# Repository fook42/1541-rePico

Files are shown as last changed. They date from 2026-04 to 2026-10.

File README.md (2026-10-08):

# 1541-rePico
replacement of analog-part of Commodore 1541-Floppy devices based on Pi-Pico(2)

## preface/credits ##
this project was derived from the original 1541-rebuild from Thorsten Kattanek (https://github.com/ThKattanek/1541-rebuild) !
parts of his code were taken from there and adopted for Raspberry Pico and modified to handle disk images differently. Thanks!

the C64/C16 selector-programm was developed and implemented by [PeiselUlli](https://github.com/peiselulli69) !

thanks to [BensonRSI](https://github.com/BensonRSI) for adding debugging documentation, dev-containers and github-magic !

## Features ##

latest version:
- software: 1.7.1
- hardware: 1.7.0

### Hardware ###

single board, size 59mm x 60 mm

- Raspberry Pico2 socket/solder-pads
- VIA 40pin socket
- levelshifter (BSS138 & 74LVC4245) for stable signals
- connectors for
  - I2C Display
  - SPI SD-Card adapter
  - Rotary-Encoder + Switch (KY-040 compatible)
  - Write-Protect-Signal

one size fits for all 1541 models.

## how to build ##

-> [interactive BOM](/hardware/bom/ibom.html)

### Software ###

#### Pico2 Firmware ####

- mounting of D64 & G64 & PRG Files
- 35 & 42 track image files supported
- read and write access for both D64 & G64
- sd-card hotswap feature (refresh of directory content)

#### C64/C16/VIC20 Image Selector ####

- browsing through sd-card content via "virtual disk-image"
  - subdirectory support
  - 4 way scrolling
- highlighting and selecting of different file-types (D64,G64,PRG,Folder)
- simple mounting and also fastloading of selected entry
- supports C64-PAL, C64-NTSC and C16 computers

## how to build ##

### prepare tools (linux) ###

```
sudo apt install cmake ninja-build libusb-1.0-0-dev build-essential pkg-config python3 xxd gcc-arm-none-eabi libnewlib-arm-none-eabi libstdc++-arm-none-eabi-newlib acme
```

### pico-sdk ###

from : <https://github.com/raspberrypi/pico-sdk>

- clone this repo
- create a environment variable called "PICO_SDK_PATH" which points to this repo
- place a "export PICO_SDK_PATH= <path to your pico-sdk>" at the end of your .profile script
- then cd into this repo-folder and initialize the mbedtls submodule (picotool mentiones this)

all in one:
```
git clone https://github.com/raspberrypi/pico-sdk.git
export PICO_SDK_PATH=$(pwd)/pico-sdk
echo "export PICO_SDK_PATH=$PICO_SDK_PATH" >> ~/.profile"
cd pico-sdk
git submodule update --init lib/mbedtls
```

### picotool ###

from : <https://github.com/raspberrypi/picotool>

- clone this repo
- install the picotool as described in README.md and BUILDING.md file there

```
git clone https://github.com/raspberrypi/picotool.git
```

### build steps ###

make sure submodules are initialized and up-to-date (like NoOS-Fat-lib)

```
git submodule update --init
git pull --recurse-submodules
```

prepare build-folder / configure Ninja for build the cmake project

```
cd firmware
mkdir build
cd build
cmake -G Ninja .. -D BUILD_MENUPRG=OFF -D COMPRESS_MENUPRG=ON -D PCB_VERSION=17
```

optional cmake variables are:

| Variable | Values | Description |
| :--- | :---: | :--- |
| BUILD_MENUPRG | ON*/OFF | let ACME compile the provided menu.asm-code. Otherwise the shipped, precompiled "menu.prg" will be used. |
| COMPRESS_MENUPRG | ON*/OFF | uses dali binary compression to generate a smaller menu-prg object |
| PCB_VERSION | 0..17* | defines which PCB version is used -> enables specific code features according to pcb-layout (like sound output) |

(* is default)

now trigger a build

```
ninja
```

## howto flash ##

connect your pico2 via USB cable and use picotool to flash the firmware

```
picotool load -t uf2 1541-rePico.uf2 -x -f
```

## debugging with OpenOCD ##

### prerequisites ###

- **CMSIS-DAP Compatible Debugger** (e.g., Raspberry Pi Debug Probe, STLink, or SEGGER J-Link) 
get binaries for a pico here : https://github.com/raspberrypi/debugprobe
- **OpenOCD** installed ( built in devcontainer or  with "build_openocd.sh")
- **gdb-multiarch** for GDB debugging ( preinstalled in devcontainer )

### setup ###

1. Connect your debugger to the Pico using the SWD pins:
   - SWCLK → GPIO 24 (or pin 20)
   - SWDIO → GPIO 25 (or pin 21)
   - GND → GND

2. Ensure the debugger is connected via USB to your development machine

### starting OpenOCD ###

Start OpenOCD in a terminal:

```
openocd -f interface/cmsis-dap.cfg -f target/rp2350.cfg
```

OpenOCD will listen on port 3333 for GDB connections.

### debugging in VS Code ###

VS Code launch configurations are available:

**Pico Debug (Cortex-Debug)** - Integrated debugging with OpenOCD

#### using Cortex-Debug (recommended) ####

Press `F5` or select "Pico Debug (Cortex-Debug)" from the Run menu. This will:
- Start OpenOCD automatically
- Load your firmware
- Break at `main()`
- Allow step debugging, breakpoints, and variable inspection

#### using external OpenOCD ####

1. Start OpenOCD in a terminal (see above)
2. Select "Pico Debug (Cortex-Debug with external OpenOCD)" from Run menu
3. VS Code will connect to the running OpenOCD instance

### useful GDB commands ###

When debugging, common GDB commands include:

```
continue         # Resume execution
step             # Step into function
next             # Step over function
break <func>     # Set breakpoint at function
break <file>:<line>  # Set breakpoint at file:line
print <var>      # Print variable value
display <var>    # Show variable on each step
backtrace        # Show call stack
```

### troubleshooting ###

**"Device not found"**: 
- Check CMSIS-DAP debugger is connected
- Verify SWD pin connections
- Try `openocd -d` for debug output
- Connect the USB for the targetdevice, then the USB for debugprobe
( to keep correct order of /dev/ttyACMx )

**GDB connection failed**: 
- Ensure OpenOCD is running on port 3333
- Check firewall settings

# documentation #

## project documentation ##

t.b.d.

## supported disk formats ##

currently [D64](/doc/D64.TXT) and [G64](/doc/G64.TXT) are supported as for reading and writing.  
as bonus, **PRG** files can be loaded by an on-the-fly routine that creates a valid D64 image out of it.

additionaly a small tool [conv_x64](/tools) is provided that allows easy conversion from one to the other on you linux-pc.

## Pictures ##

impressions of current setup and PCB can be found [here](/doc/pictures).

## Links ##

- great collection of basics about disk-image-formats can be found here:  
<https://ist.uwaterloo.ca/~schepers/formats.html>

- forum64 project discussion thread (base of 1541-rebuild and 1541-rePico)  
<https://www.forum64.de/index.php?thread/59884-laufwerk-der-1541-emulieren>

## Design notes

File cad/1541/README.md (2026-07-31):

# 1541-Front Bezel

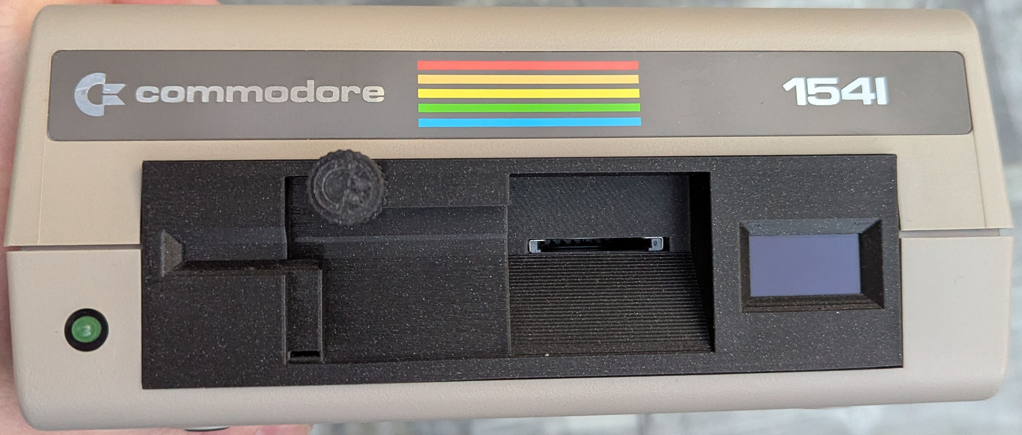
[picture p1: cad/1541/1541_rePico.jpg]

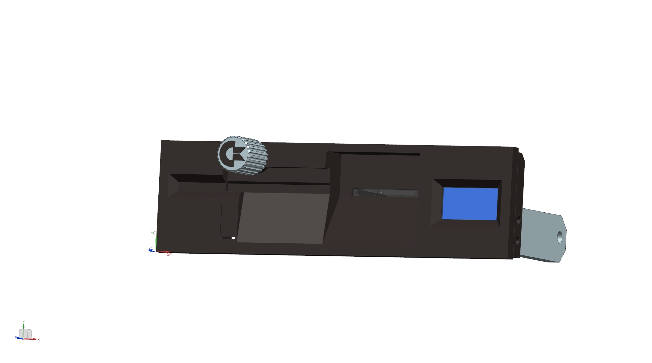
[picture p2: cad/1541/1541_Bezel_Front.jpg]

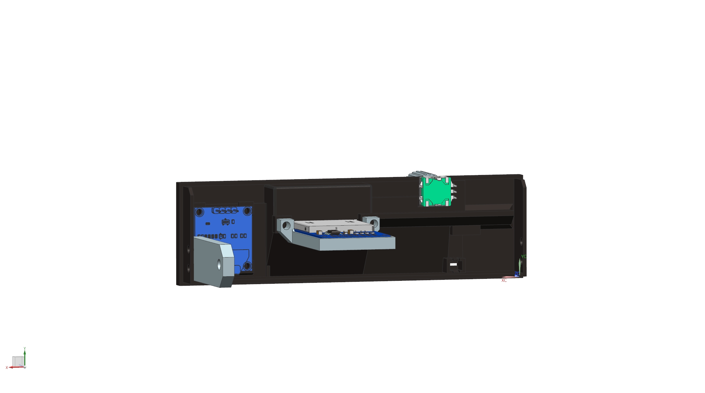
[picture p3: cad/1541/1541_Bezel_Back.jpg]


## CAD Files for printing

| Amount | Part |
| :--- | :---: |
| 1 | 1541_Bezel.stp | 
| 1 | SD_Tray.stp |
| 1 | Knob.stp |
| 2 | 2xSide_Holder_LR.stp |

### Print Settings

|Orientation (Bezel)| 45 deg |
| :--- | :---: |
|Layer Height | 0.15 |
|Wall loops | 5 |
|Top shell Layers |5|
|Bottom shell Layers |5|
|Infill density |20%|
|Infill pattern |Grid|

### Print Direction

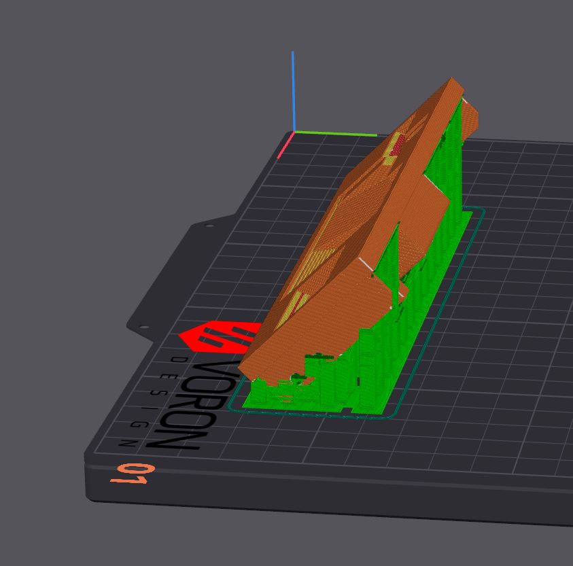
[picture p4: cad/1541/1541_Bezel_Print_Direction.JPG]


## BOM

| Front Bezel | |
| :--- | :---: |
| Amount | Part |
| 2 | Heat Set Insert Nut M3 x D5.0 mm x L4.0 mm |

| Display | |
| :--- | :---: |
| Amount | Part |
| 4 | Selftapping M2.6 x 6mm | 

| SD-Card Tray | |
| :--- | :---: |
| Amount | Part |
| 2 | Selftapping M2 x 5 mm | 
| 2 | BHCS M3 x 8 mm | 

| Side Holder | |
| :--- | :---: |
| Amount | Part |
| 6 | BHCS M3 x 6 mm | 
| 2 | M3 Washer | 
| 6 | Heat Set Insert Nut M3 x D5.0 mm x L4.0 mm |

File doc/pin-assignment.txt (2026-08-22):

### 1541-rePico Mapping ###
## (stand: 2026-08-06)

pico2 PIN-mapping:
# 17 für die VIA6522 Verbindung (PA0-PA7, BRDY, SYNC, SOE, SOE_GA, WP, MTR, STP0, STP1, OE)
SOE  = GP0
OE   = GP1
SYNC = GP2
SOE_GA = GP3
MTR  = GP4
WPS  = GP5
STP0 = GP6
STP1 = GP7
PA0  = GP8
PA1  = GP9
PA2  = GP10
PA3  = GP11
PA4  = GP12
PA5  = GP13
PA6  = GP14
PA7  = GP15
BRDY = GP22

# 4 für die SD-Karte (SPI)
MISO = GP16
CS   = n.c. (nicht belegt)
SCK  = GP18
MOSI = GP19

# 2 fürs Display (nur per I2C angeschlossen)
SDA  = GP20
SCL  = GP21

# 3 für den Drück-Dreh-Schalter
BT1  = GP27
BT2  = GP26
BT3  = GP28

# Anschluss Sound-Buzzer
SOUND = GP17

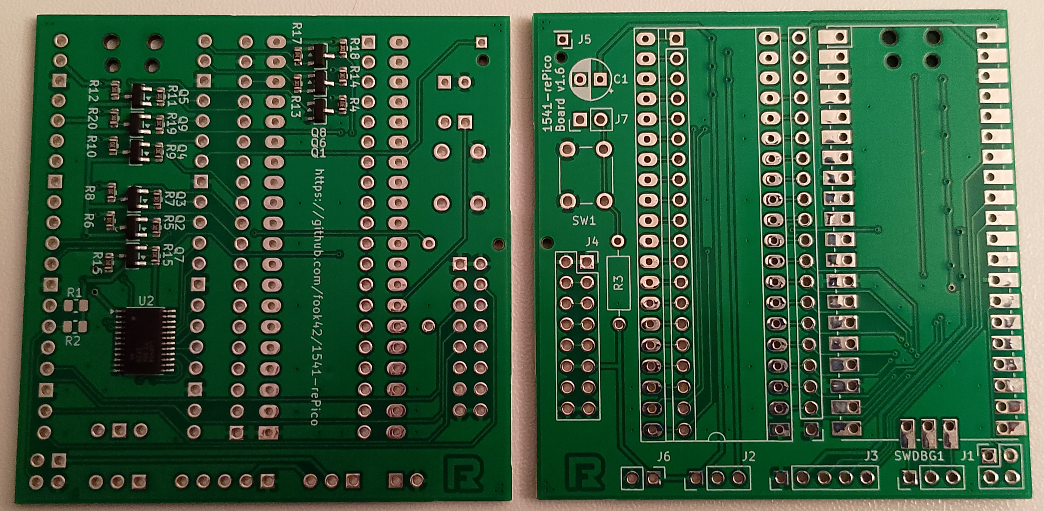
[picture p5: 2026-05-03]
doc/pictures/PCB_version16.jpg

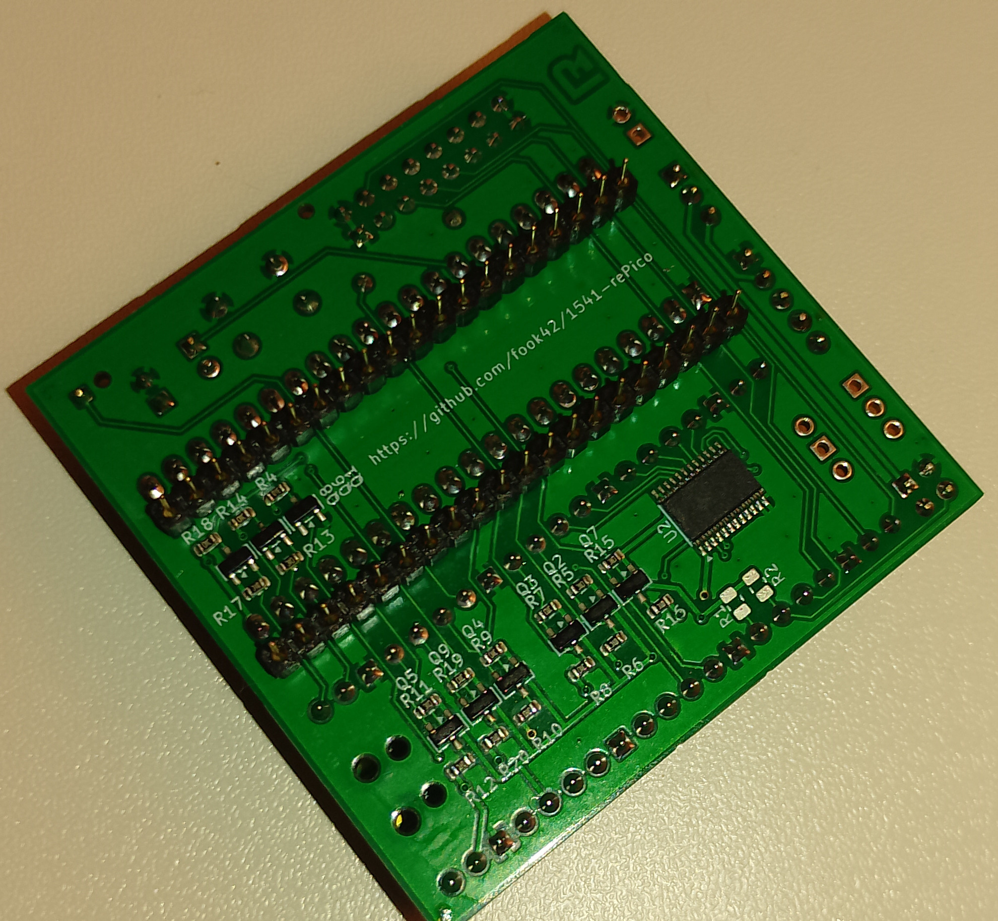
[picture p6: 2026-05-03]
doc/pictures/RePico_v16_bottom.jpg

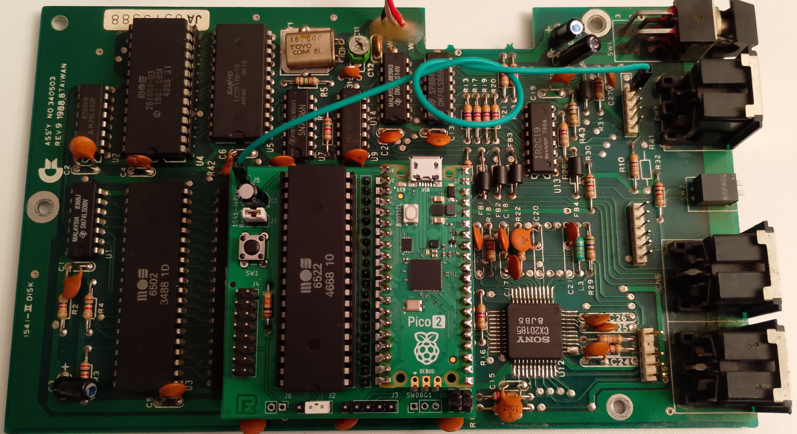
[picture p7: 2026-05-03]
doc/pictures/1541-II_with_rePico.jpg

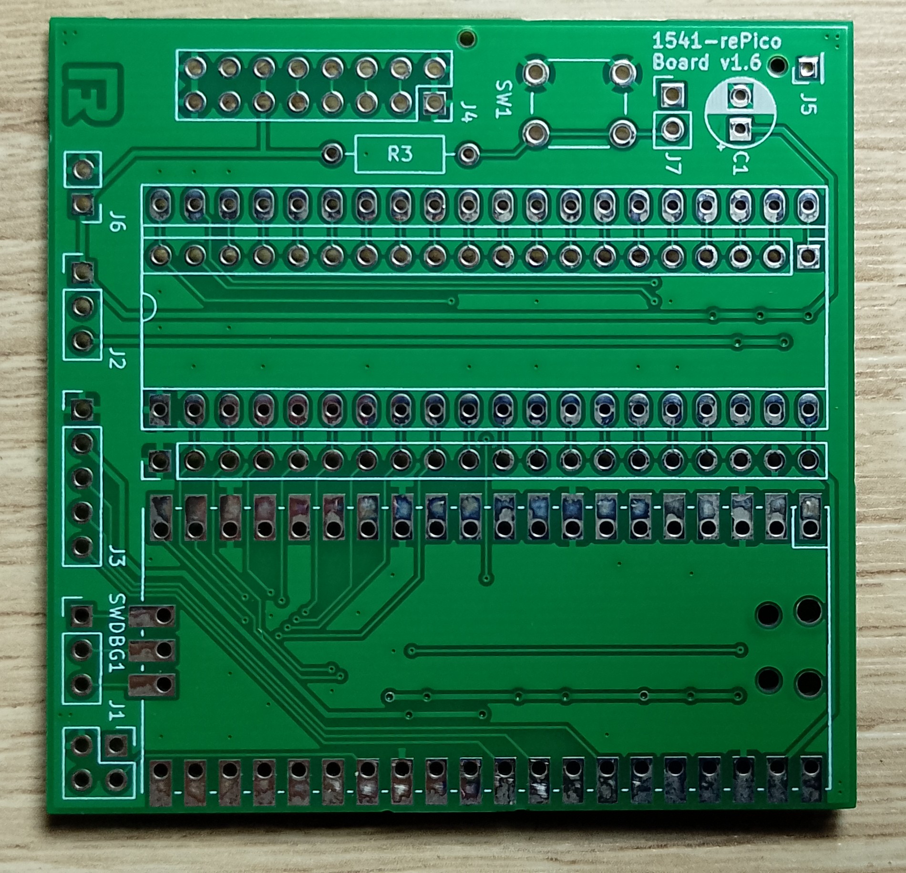
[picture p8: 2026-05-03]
doc/pictures/PCB_V16_top.jpg

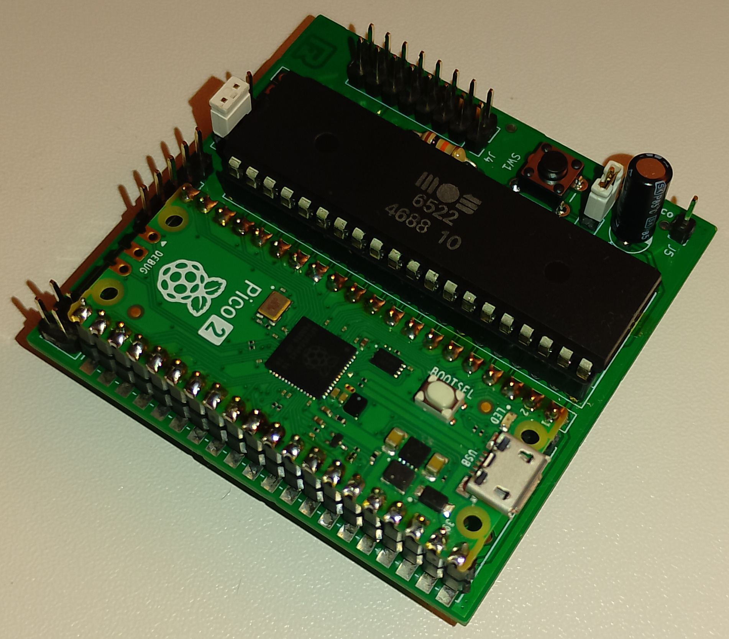
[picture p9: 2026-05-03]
doc/pictures/RePico_v16_top.jpg

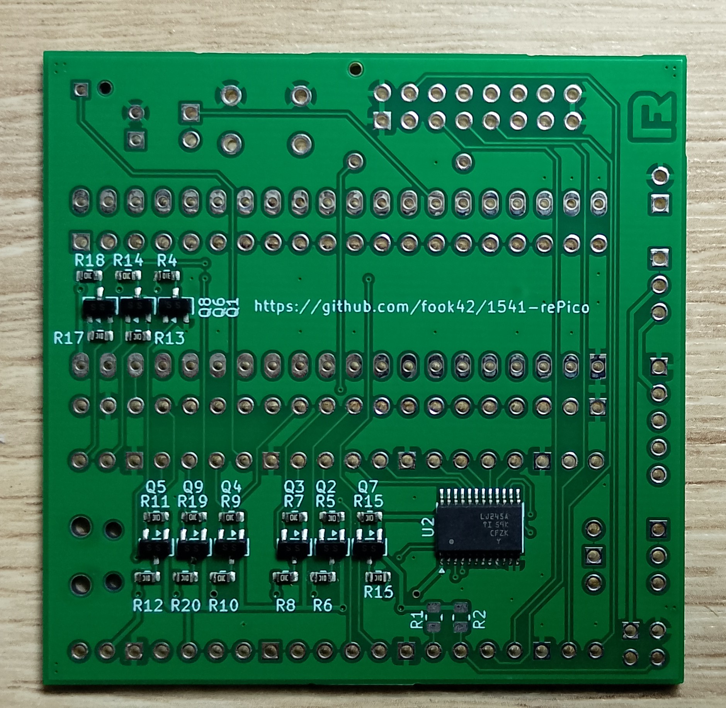
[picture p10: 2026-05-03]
doc/pictures/PCB_V16_bottom.jpg

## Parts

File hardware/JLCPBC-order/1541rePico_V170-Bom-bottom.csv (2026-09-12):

Comment | Designator | Footprint | JLCPCB Part #
1M | R4 | Resistor_SMD:R_0603_1608Metric | C22935
SN74LVC4245A | U2 | Package_SO:TSSOP-24_4.4x7.8mm_P0.65mm | C7859
BSS138 | Q1,Q2,Q3,Q4,Q5,Q6,Q7,Q8,Q9 | Package_TO_SOT_SMD:SOT-23 | C7420339
10k | R5,R6,R7,R8,R9,R10,R11,R12,R13,R14,R15,R16,R17,R18,R19,R20 | Resistor_SMD:R_0603_1608Metric | C25804

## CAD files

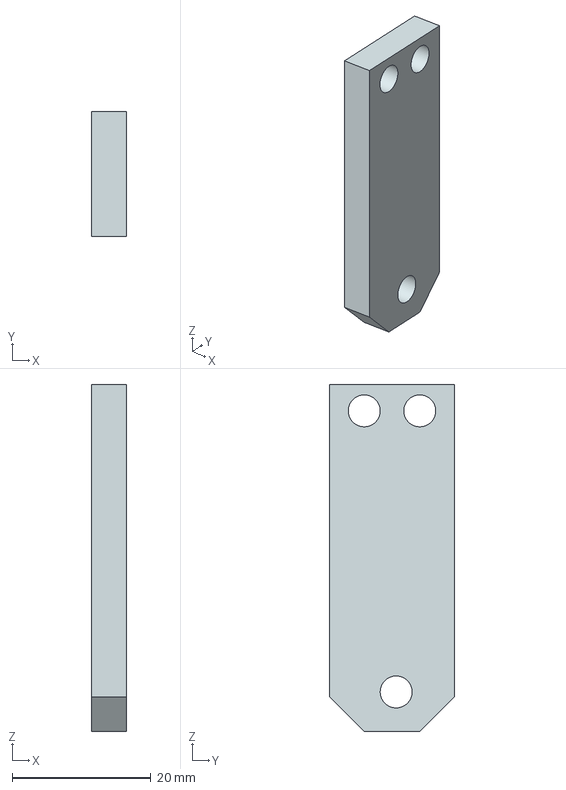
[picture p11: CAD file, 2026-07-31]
cad/1541/2xSide_Holder_LR.stp
5.00 x 18.0 x 50.0 mm

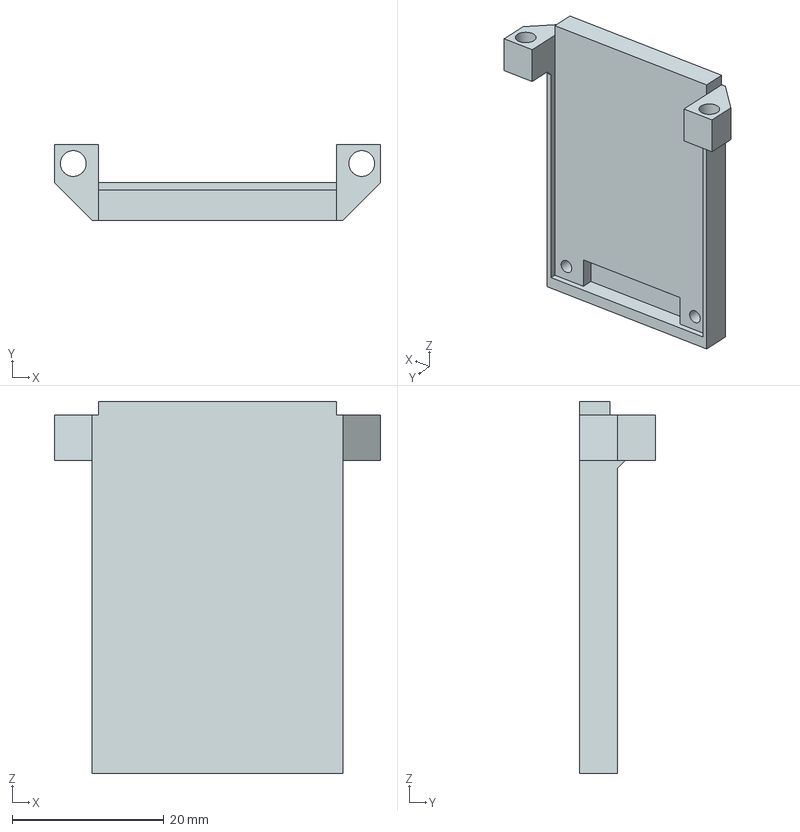
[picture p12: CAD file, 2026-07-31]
cad/1541/SD_Card_Tray.stp
43.0 x 10.0 x 49.0 mm

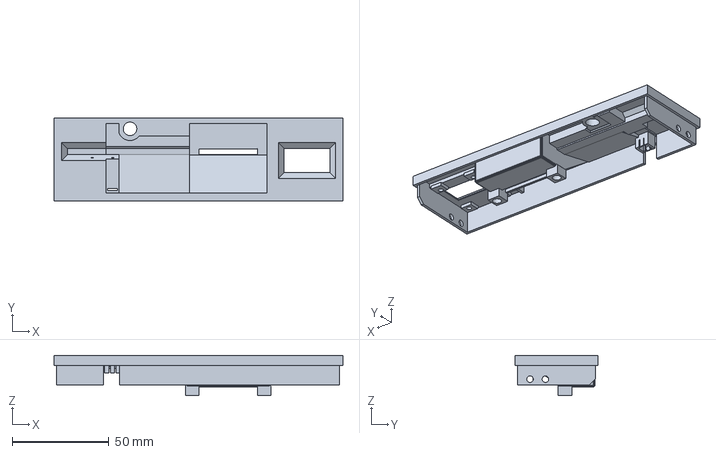
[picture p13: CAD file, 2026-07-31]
cad/1541/1541_Bezel.stp
149.2 x 43.0 x 20.8 mm

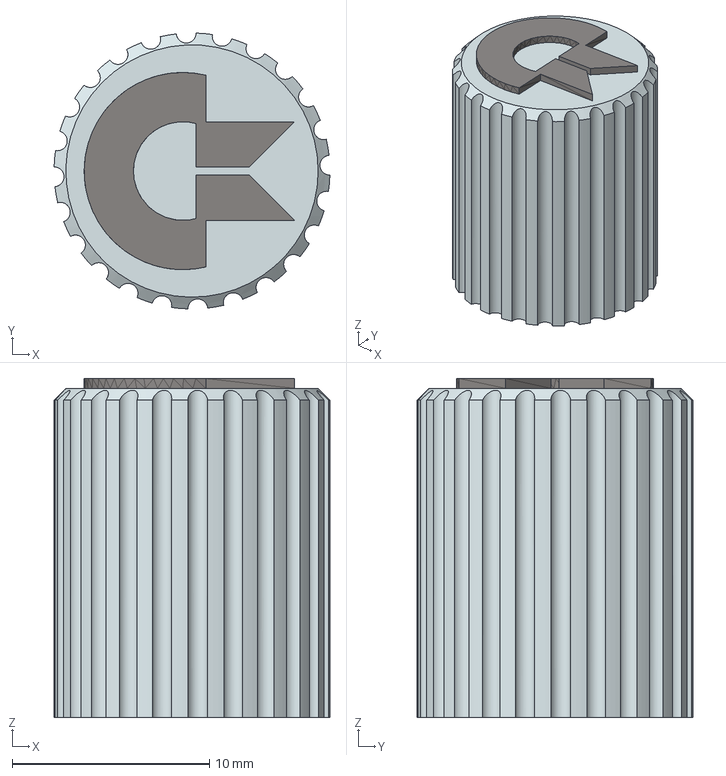
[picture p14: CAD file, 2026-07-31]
cad/1541/Knob.stp
14.0 x 14.0 x 17.2 mm

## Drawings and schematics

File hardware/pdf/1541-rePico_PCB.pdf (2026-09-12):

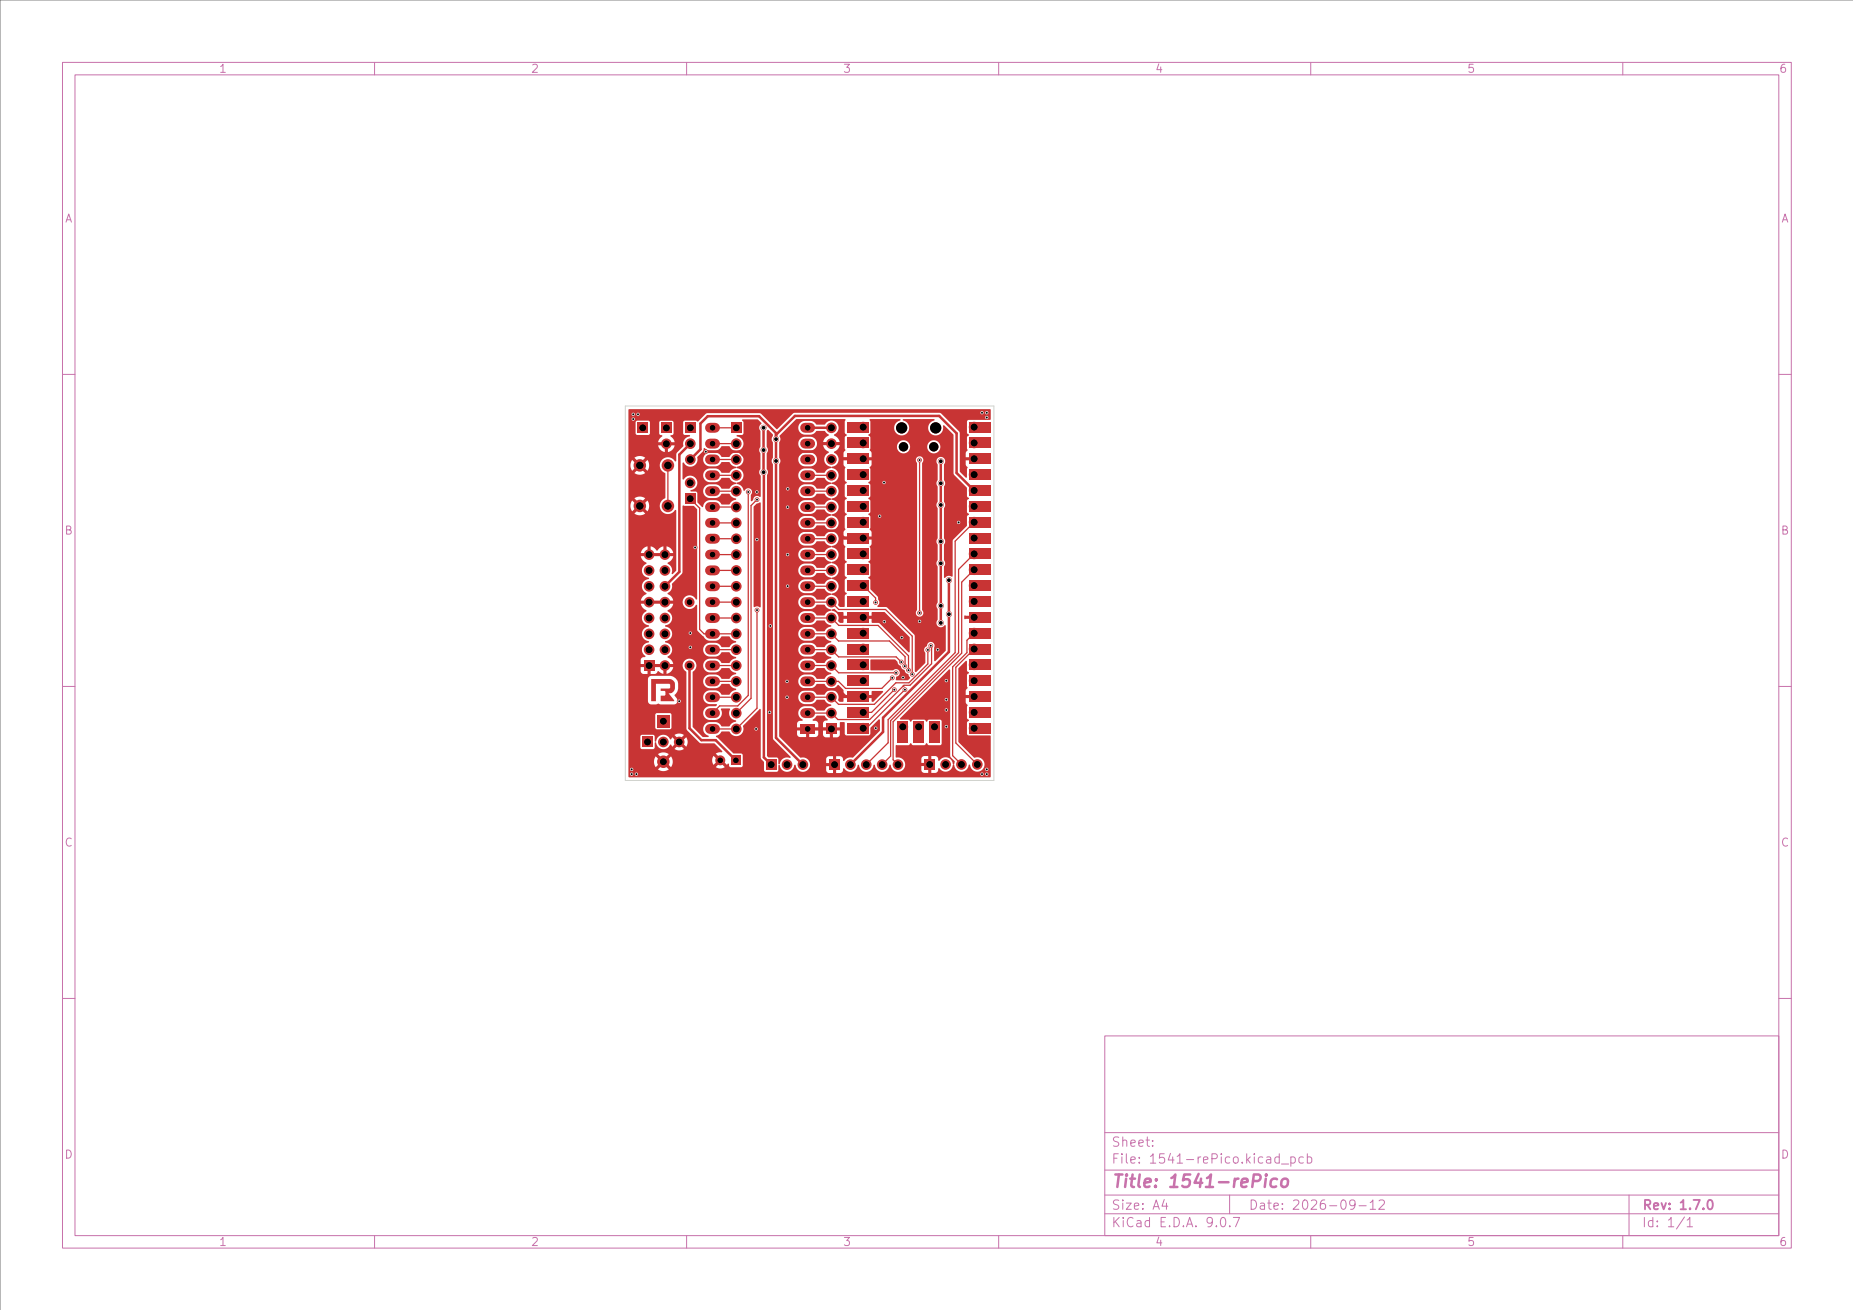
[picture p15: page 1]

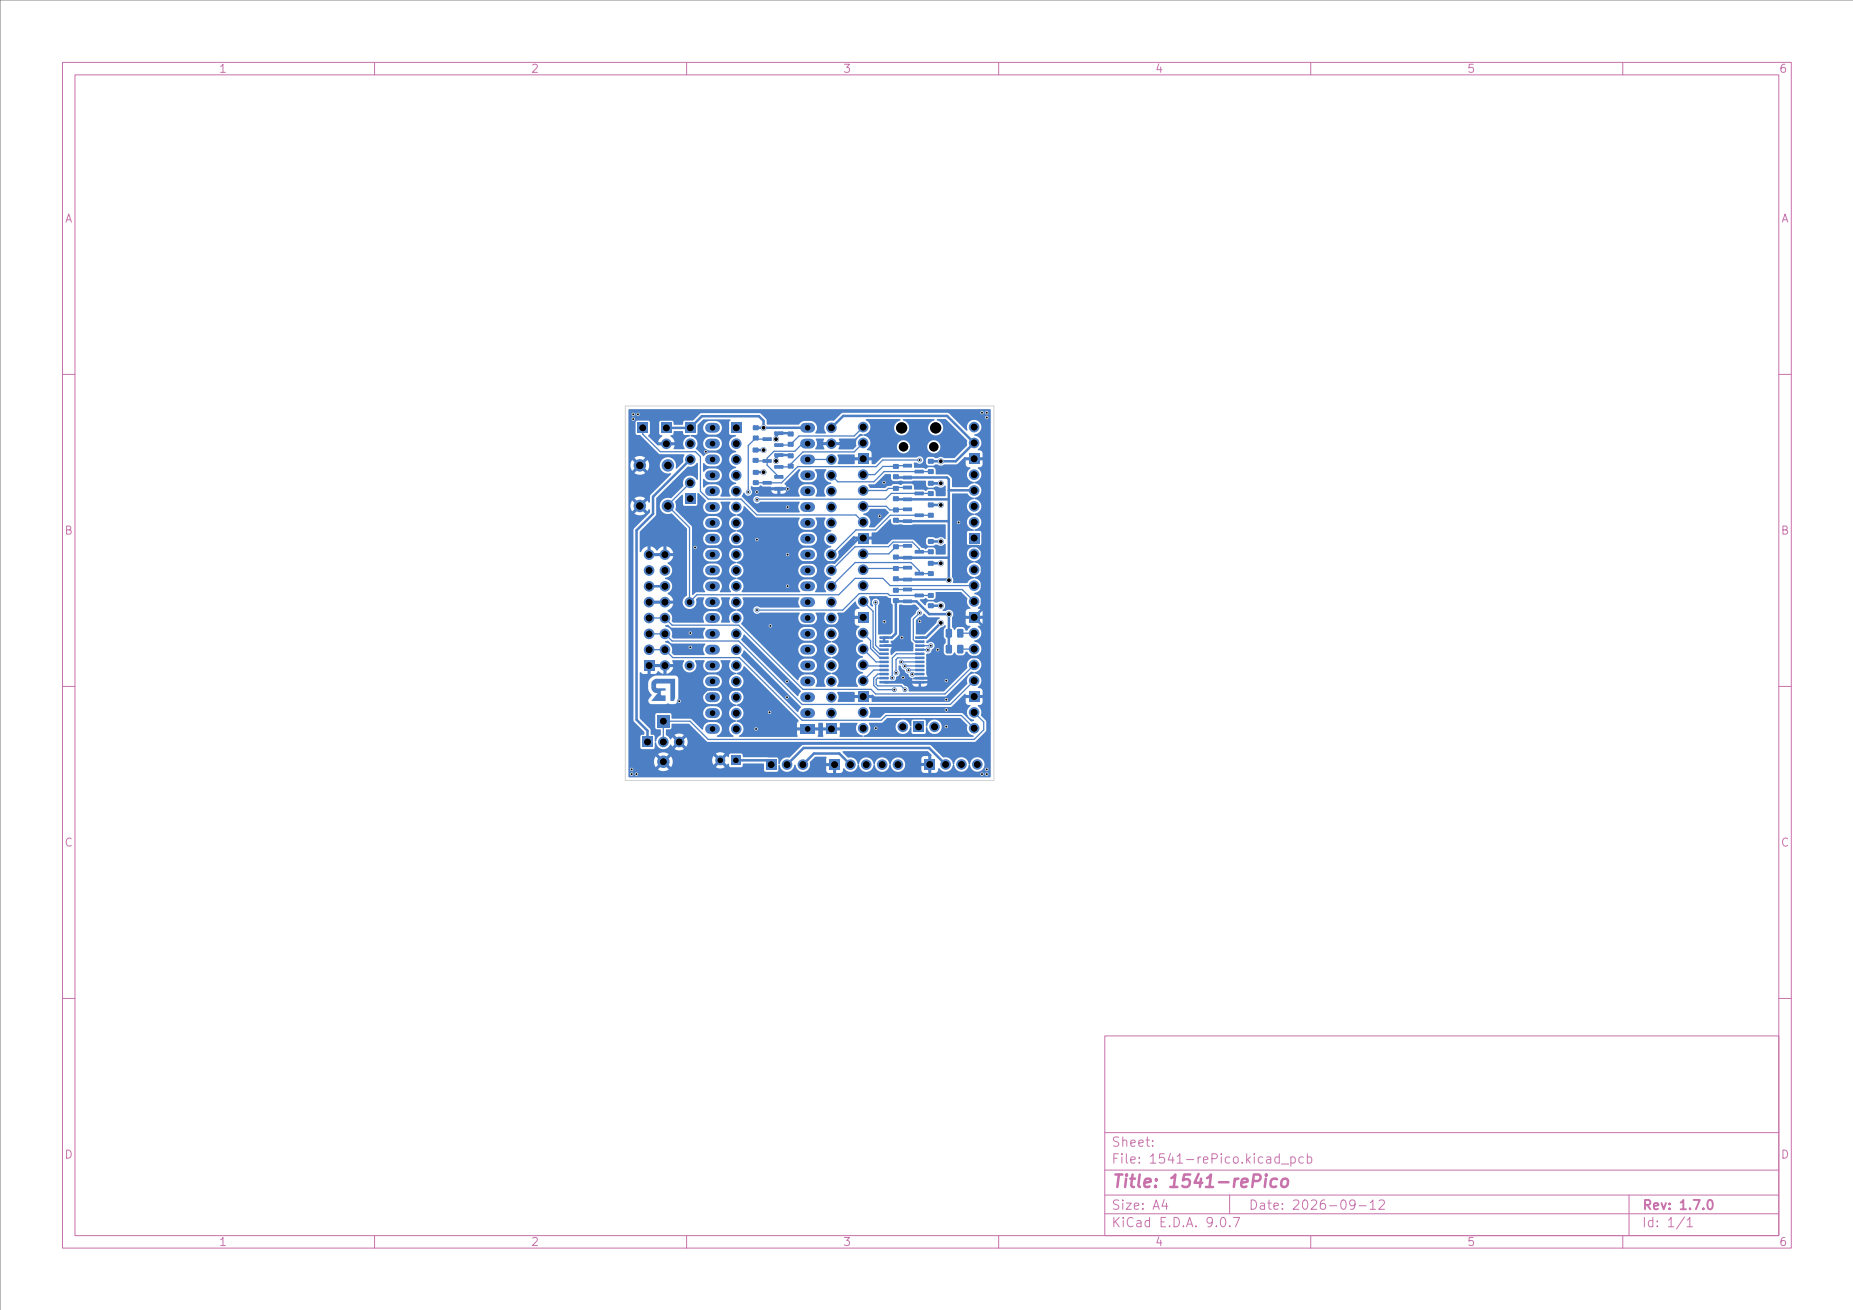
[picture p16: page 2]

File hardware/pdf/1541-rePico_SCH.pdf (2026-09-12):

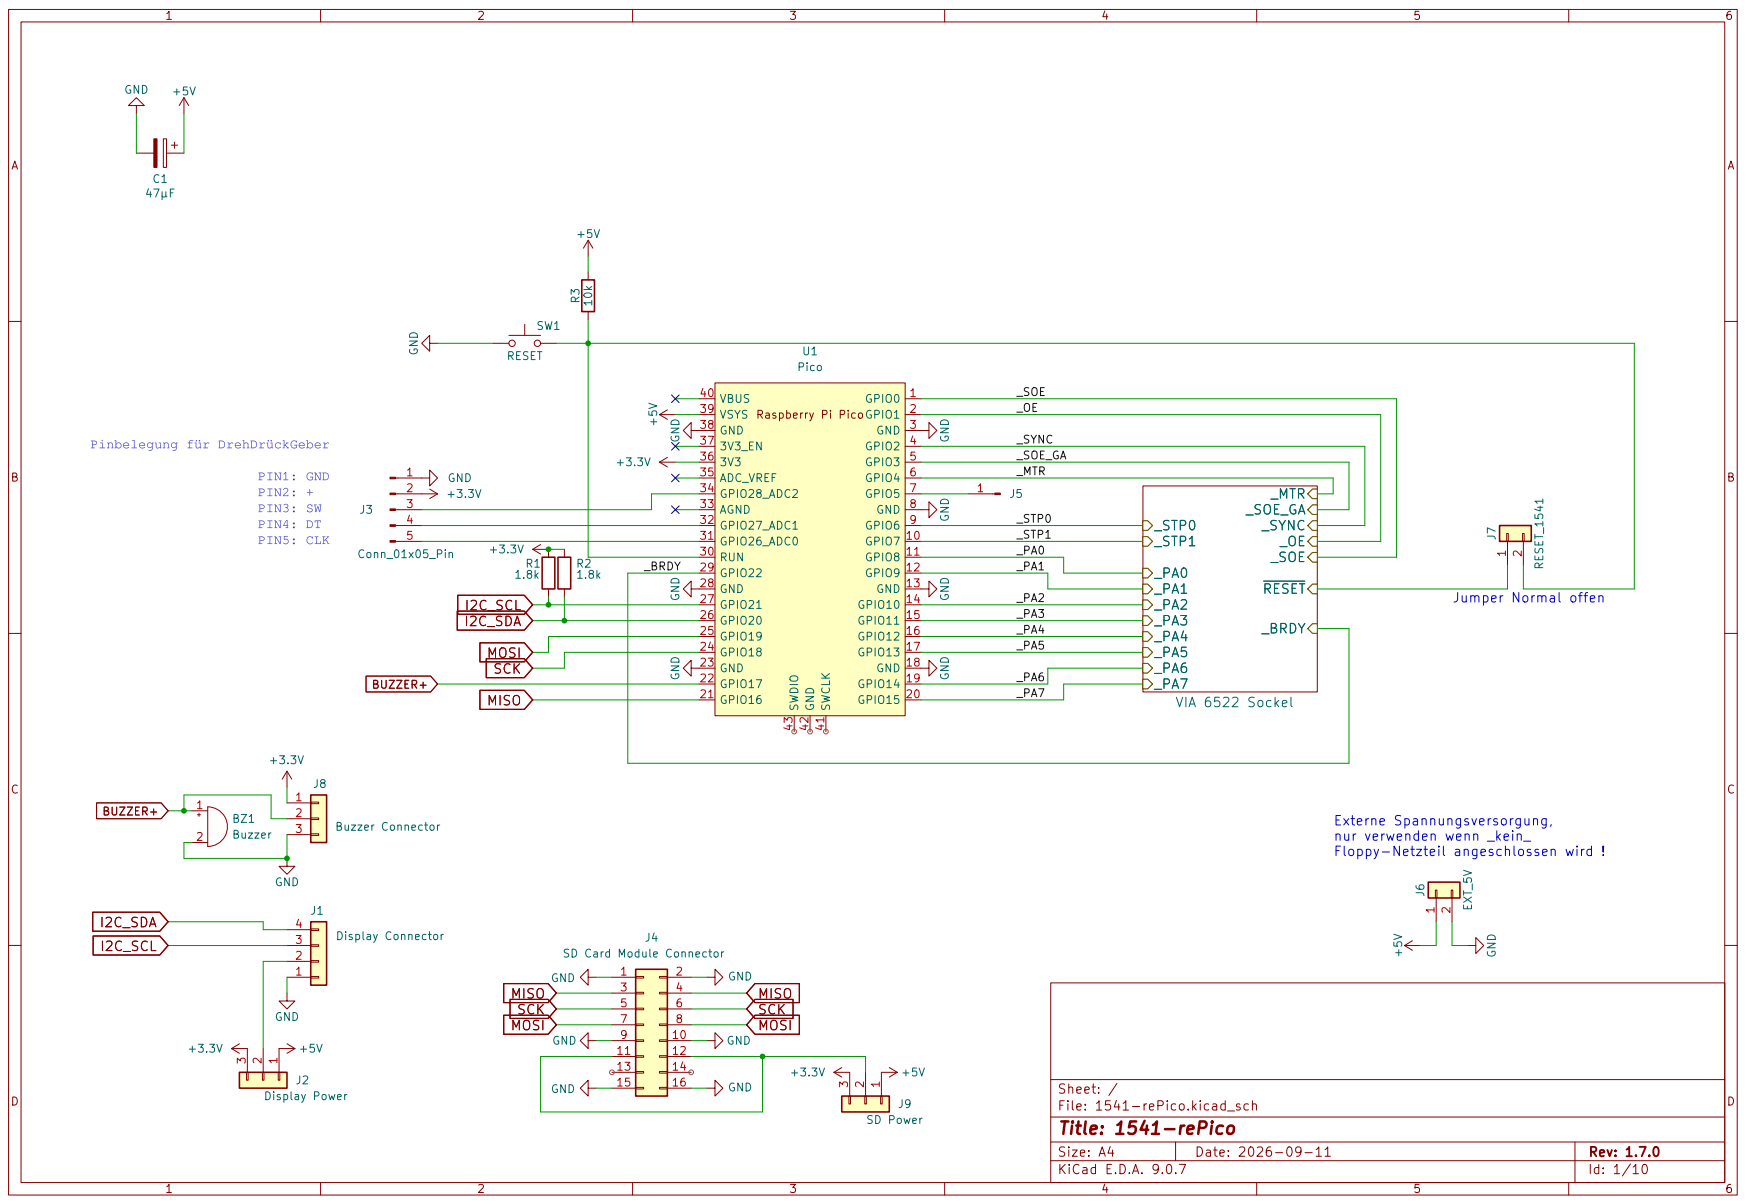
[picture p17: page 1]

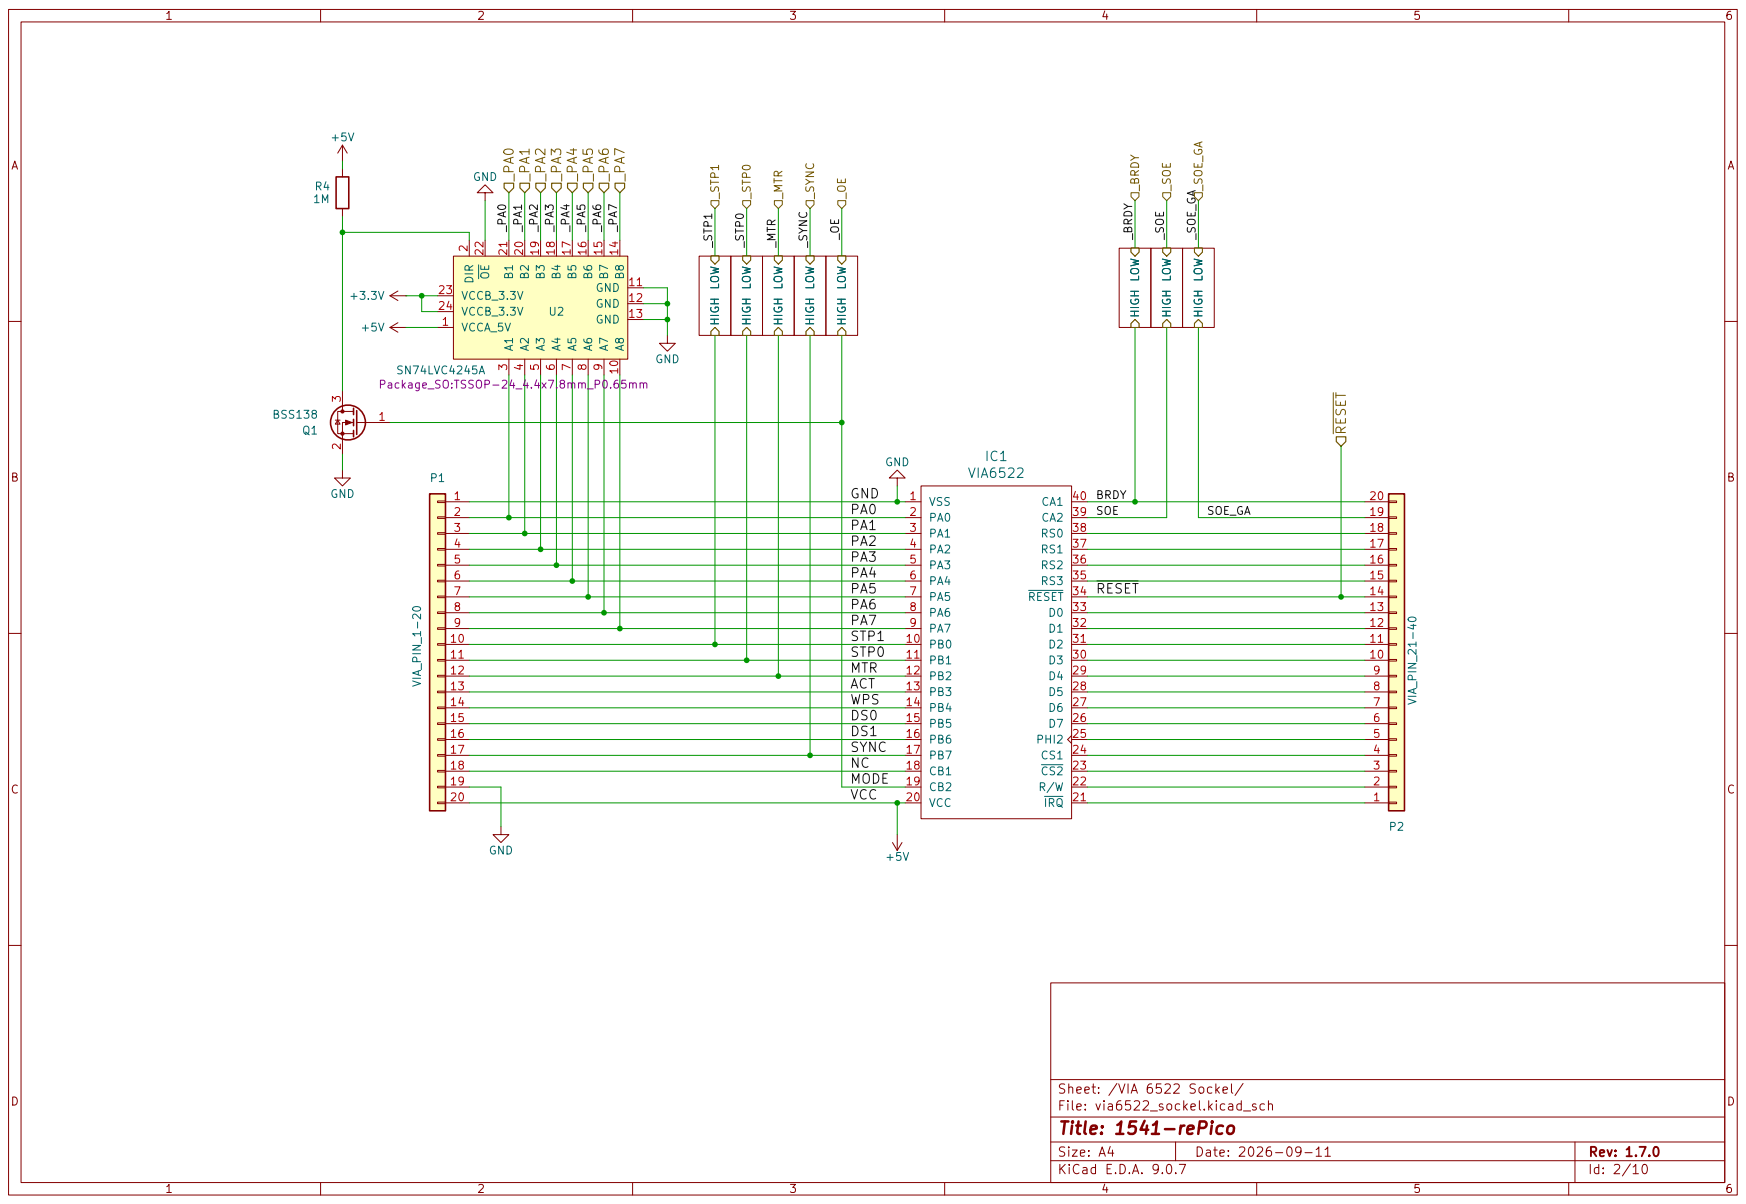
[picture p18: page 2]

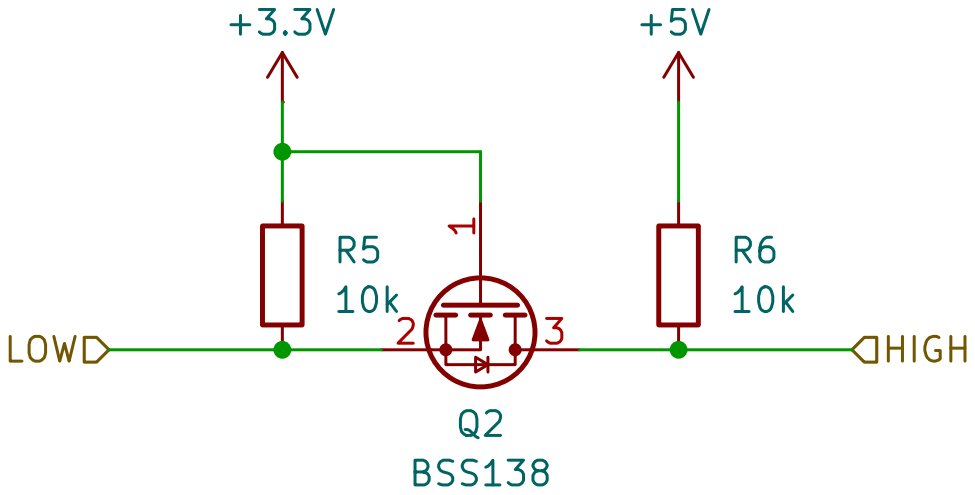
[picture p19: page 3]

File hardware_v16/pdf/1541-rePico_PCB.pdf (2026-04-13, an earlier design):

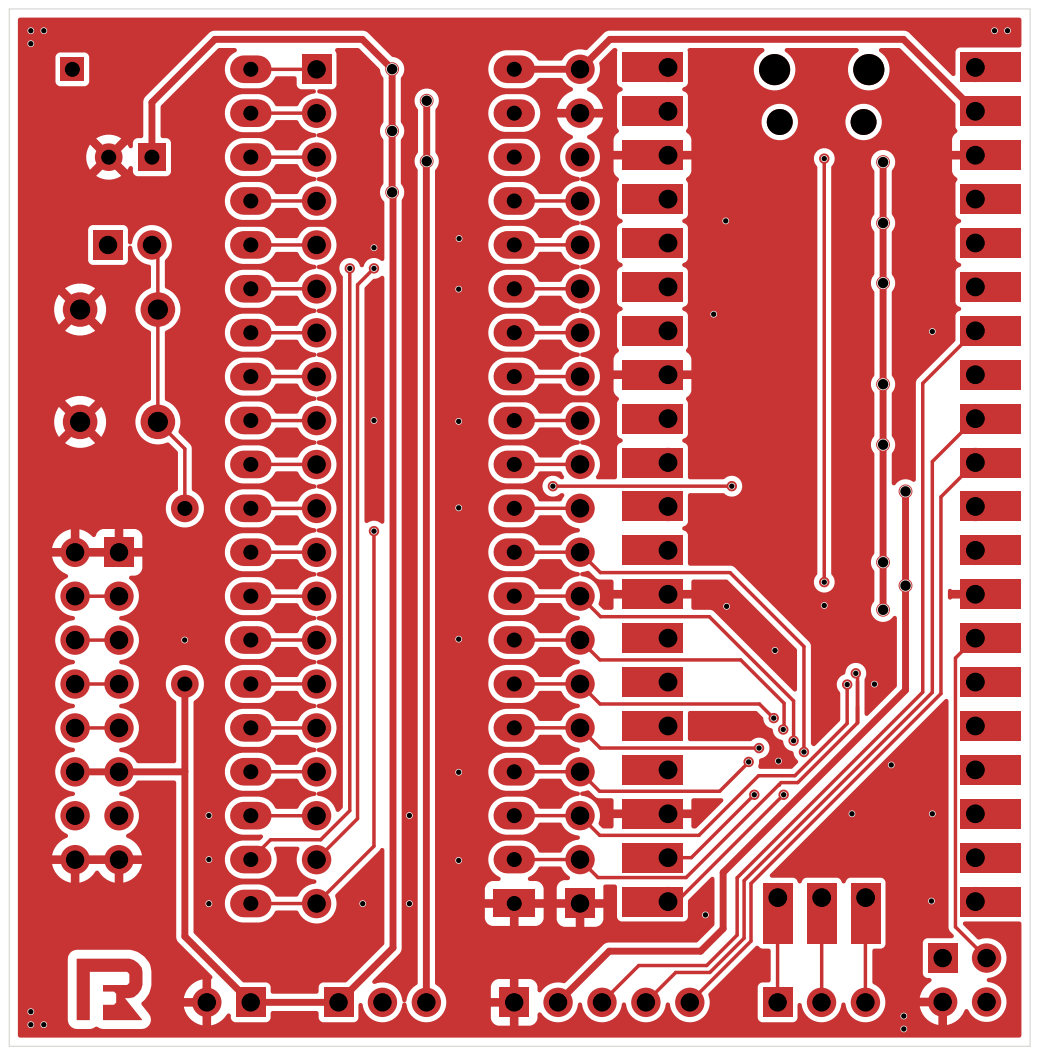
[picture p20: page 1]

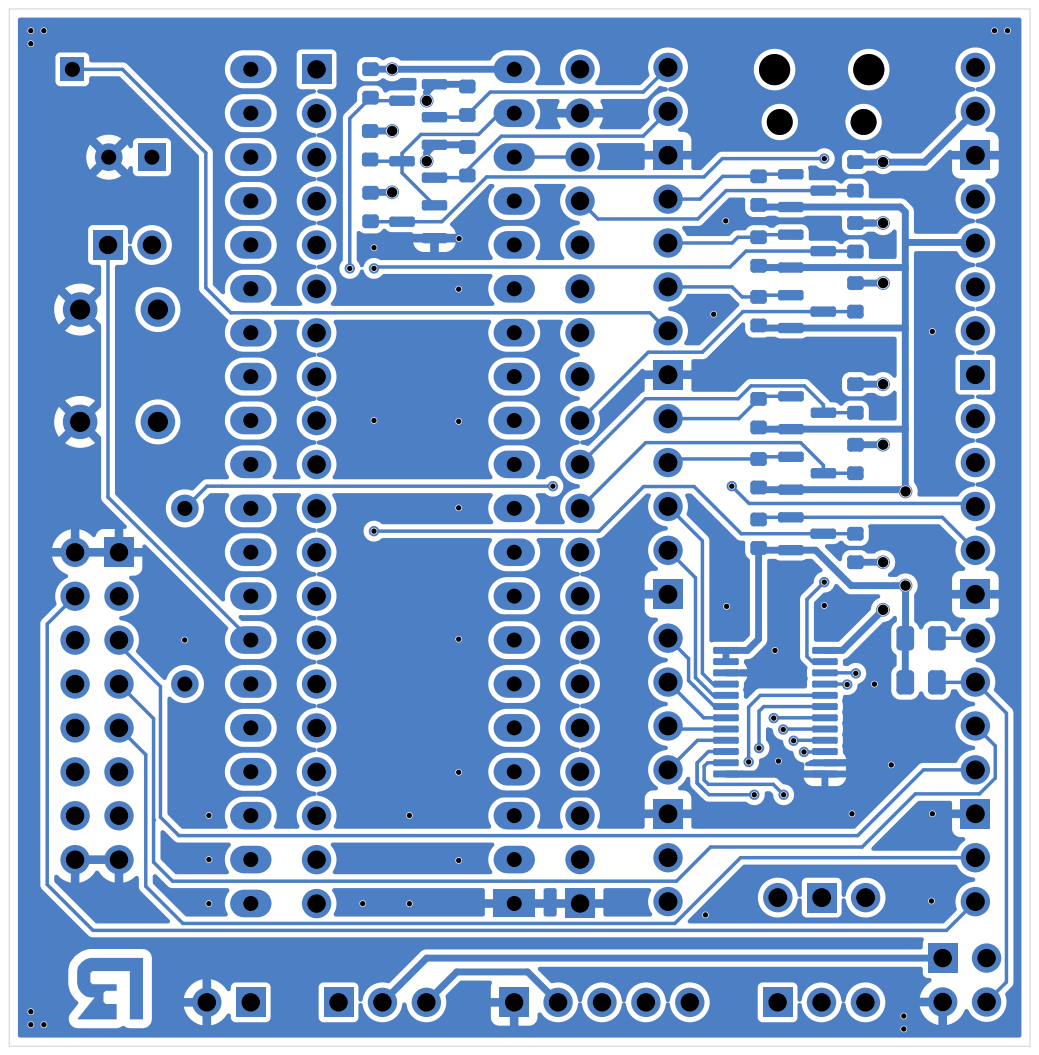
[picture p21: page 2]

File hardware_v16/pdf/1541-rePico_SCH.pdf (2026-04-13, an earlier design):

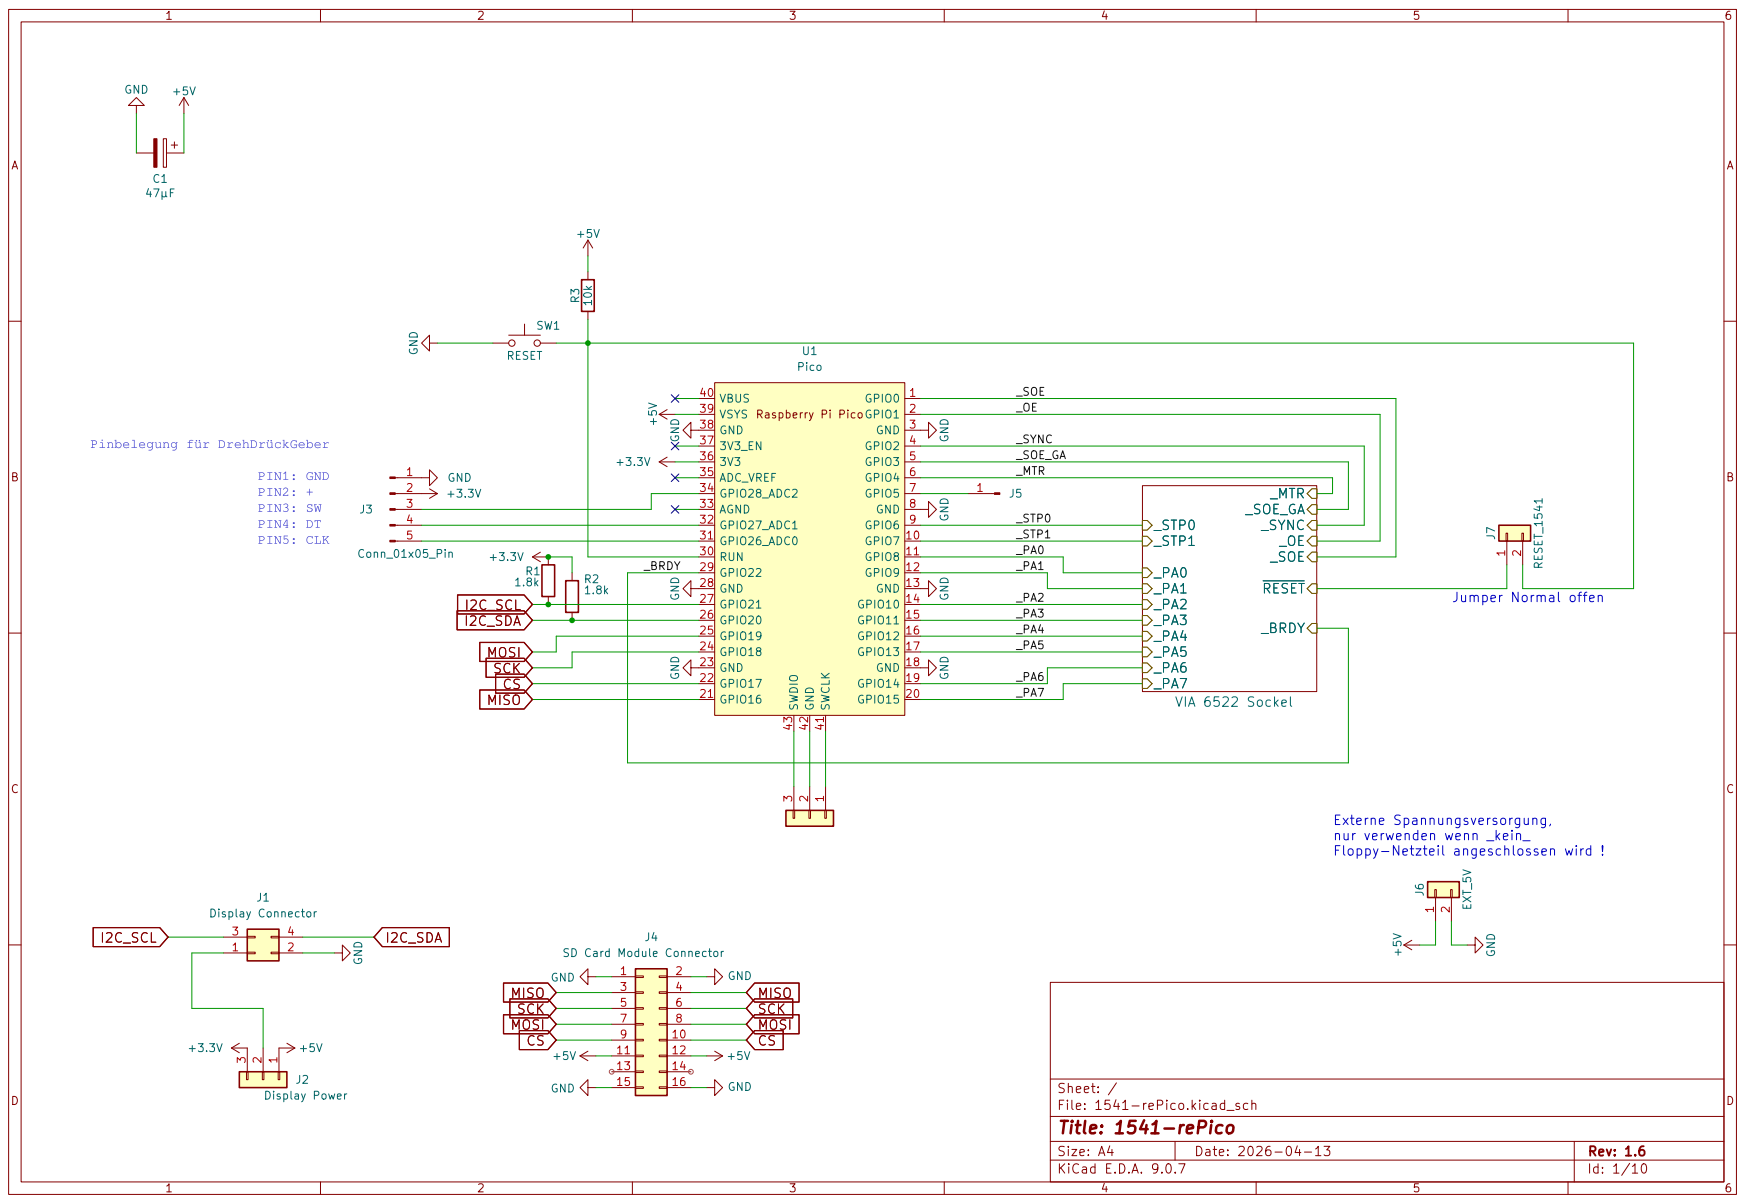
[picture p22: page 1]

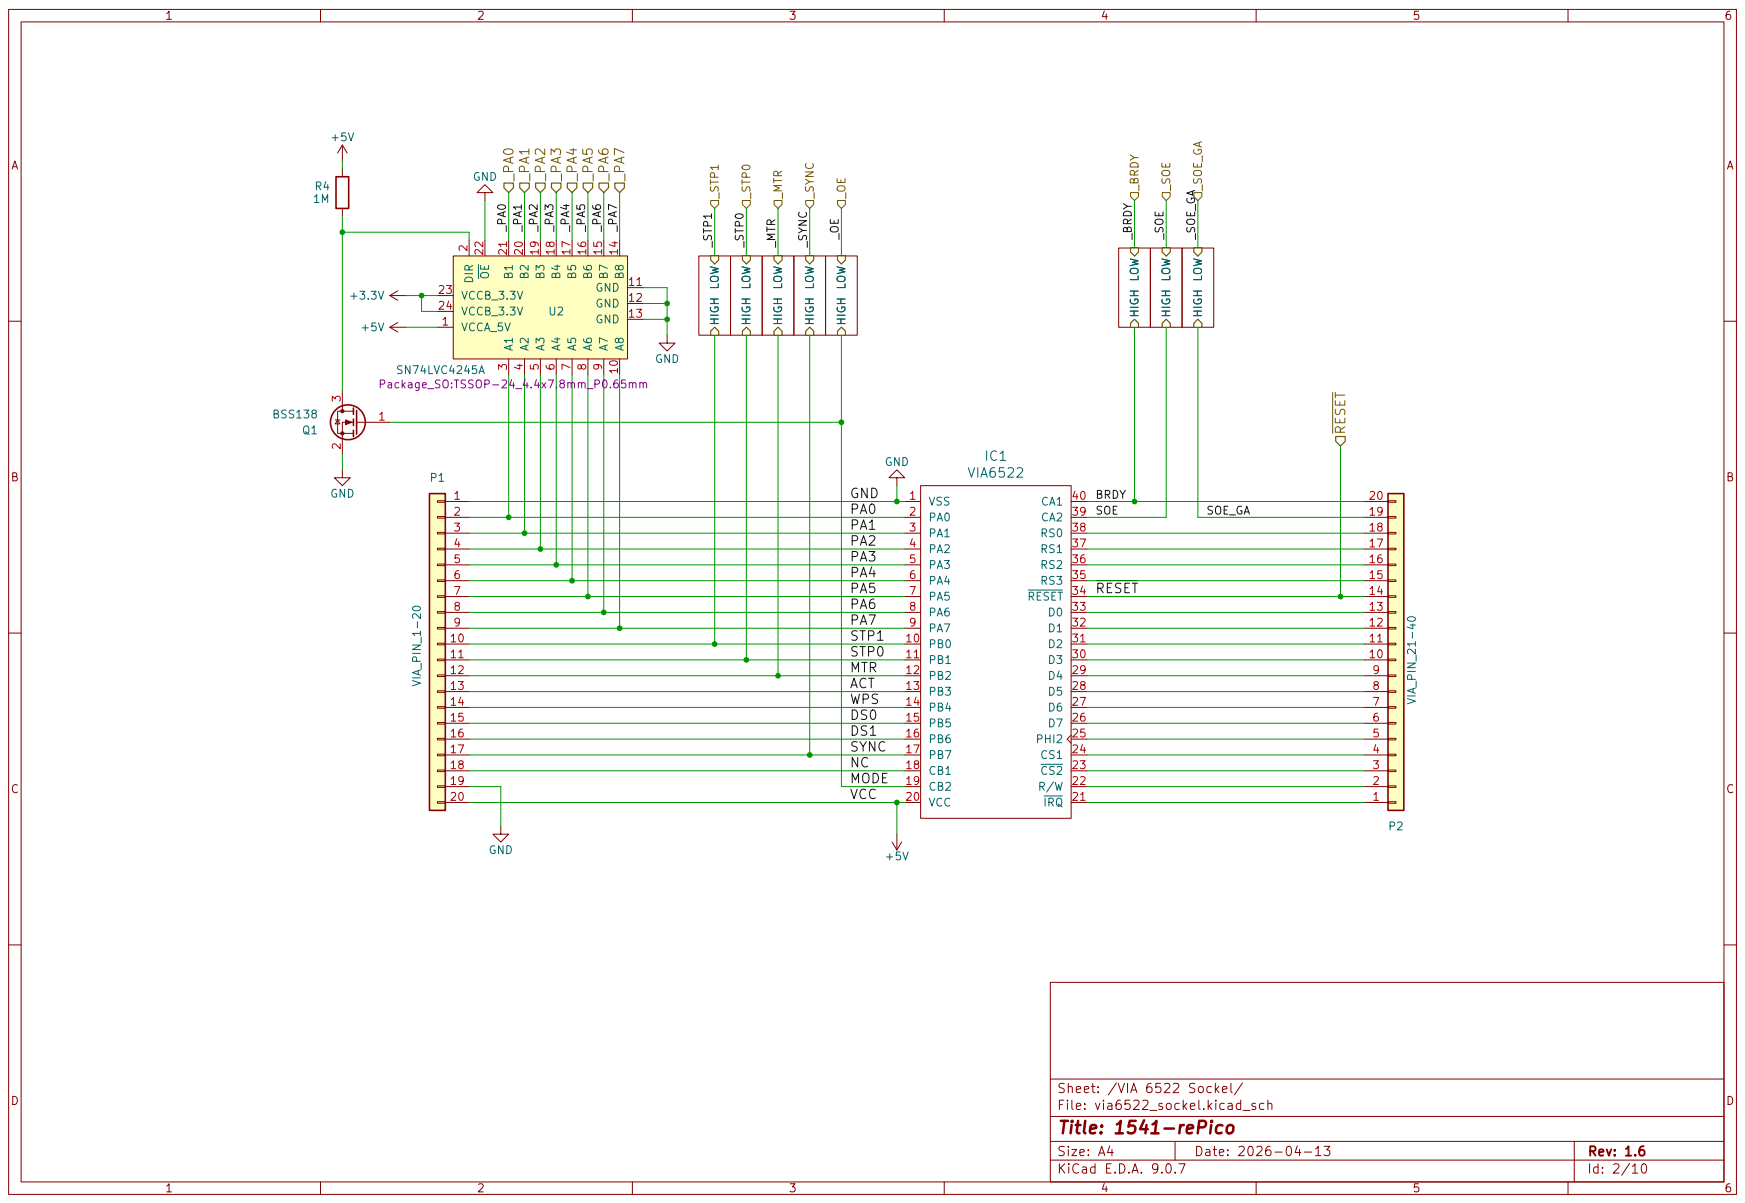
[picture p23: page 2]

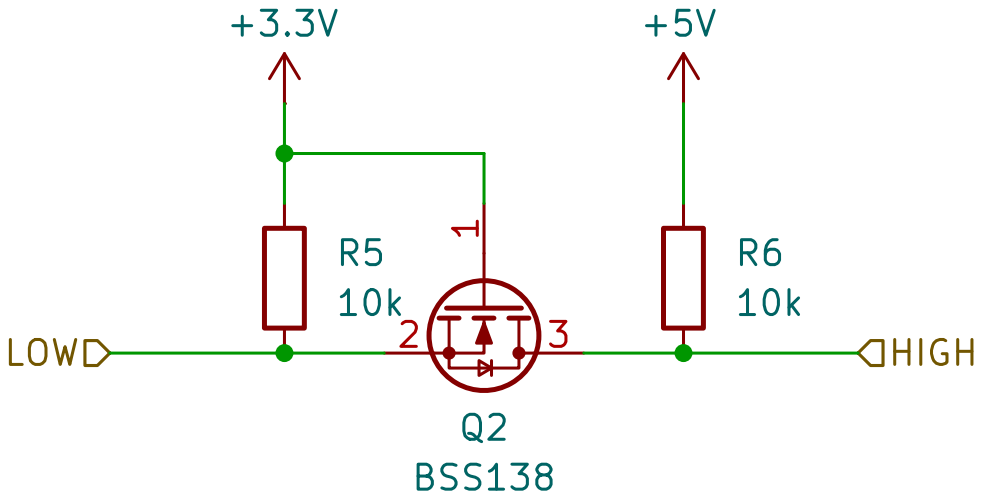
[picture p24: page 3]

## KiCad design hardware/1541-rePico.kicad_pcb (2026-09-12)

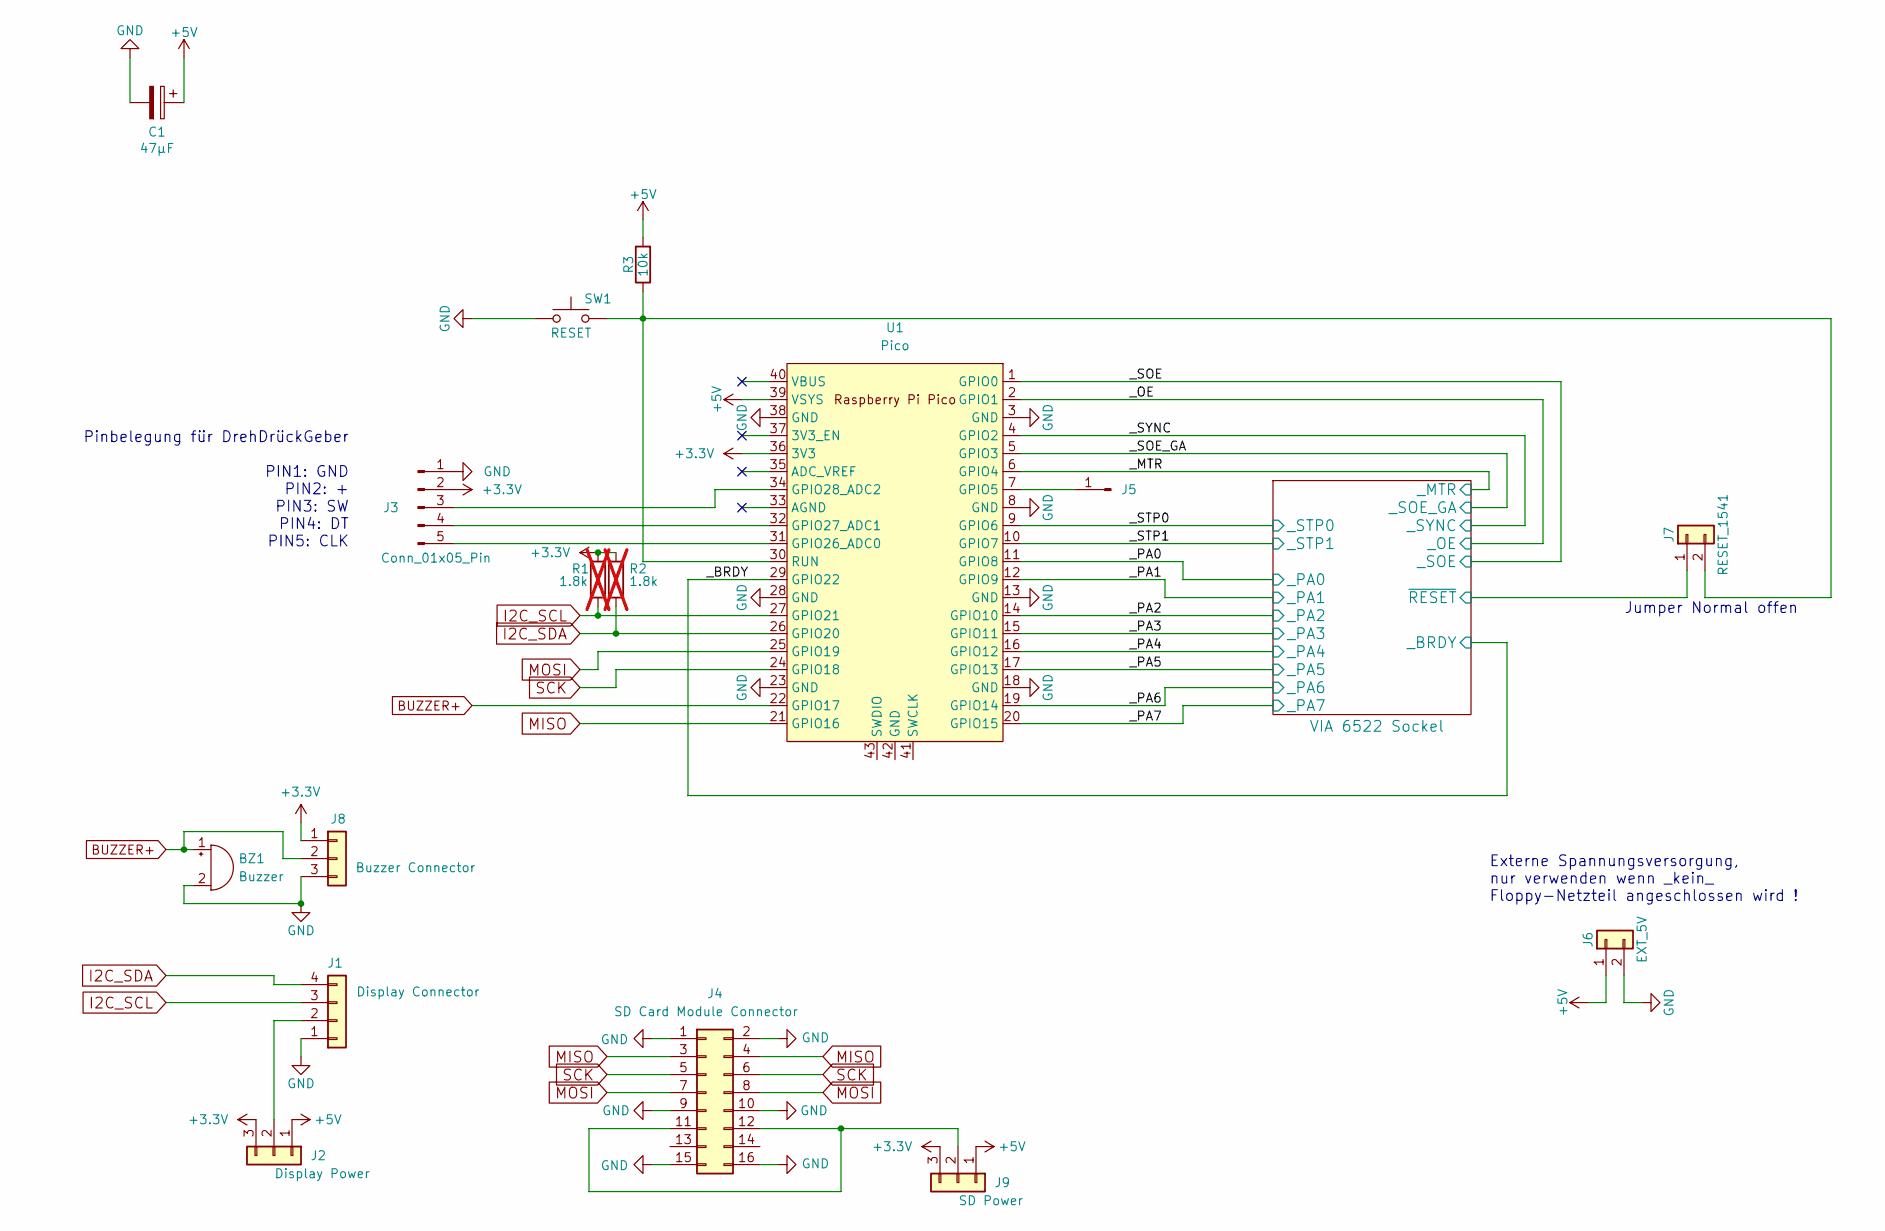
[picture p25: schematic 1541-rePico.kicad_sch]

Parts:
BZ1: Buzzer; MagneticBuzzer_StarMicronics_QMX
C1: 47µF; CP_Radial_D5.0mm_P2.50mm
J1: Display Connector; PinSocket_1x04_P2.54mm_Vertical
J2: Display Power; PinHeader_1x03_P2.54mm_Vertical
J3: Conn_01x05_Pin; PinHeader_1x05_P2.54mm_Vertical
J4: SD Card Module Connector; PinSocket_2x08_P2.54mm_Vertical
J5: Conn_01x01_Pin; PinHeader_1x01_P2.54mm_Vertical
J6: EXT_5V; PinHeader_1x02_P2.54mm_Vertical
J7: RESET_1541; PinHeader_1x02_P2.54mm_Vertical
J8: Buzzer Connector; PinHeader_1x03_P2.54mm_Vertical
J9: SD Power; PinHeader_1x03_P2.54mm_Vertical
R1, R2: 1.8k; R_0805_2012Metric; not fitted
R3: 10k; R_Axial_DIN0207_L6.3mm_D2.5mm_P10.16mm_Horizontal
SW1: RESET; SW_PUSH_6mm_H5mm
U1: Pico; RPi_Pico_SMD_TH

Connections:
+3.3V: J2.3, J3.2, J8.1, J9.3, R1.1, R2.1, U1.36 (3V3); also elsewhere on the board
+5V: C1.1, J2.1, J6.1, J9.1, R3.2, U1.39 (VSYS); also elsewhere on the board
/VIA 6522 Sockel/~RESET: J7.1; also elsewhere on the board
/_BRDY: U1.29 (GPIO22); also elsewhere on the board
/_MTR: U1.6 (GPIO4); also elsewhere on the board
/_OE: U1.2 (GPIO1); also elsewhere on the board
/_PA0: U1.11 (GPIO8); also elsewhere on the board
/_PA1: U1.12 (GPIO9); also elsewhere on the board
/_PA2: U1.14 (GPIO10); also elsewhere on the board
/_PA3: U1.15 (GPIO11); also elsewhere on the board
/_PA4: U1.16 (GPIO12); also elsewhere on the board
/_PA5: U1.17 (GPIO13); also elsewhere on the board
/_PA6: U1.19 (GPIO14); also elsewhere on the board
/_PA7: U1.20 (GPIO15); also elsewhere on the board
/_SOE: U1.1 (GPIO0); also elsewhere on the board
/_SOE_GA: U1.5 (GPIO3); also elsewhere on the board
/_STP0: U1.9 (GPIO6); also elsewhere on the board
/_STP1: U1.10 (GPIO7); also elsewhere on the board
/_SYNC: U1.4 (GPIO2); also elsewhere on the board
BUZZER+: BZ1.1 (+), J8.2, U1.22 (GPIO17)
GND: BZ1.2 (-), C1.2, J1.1, J3.1, J4.1, J4.2, J4.9, J4.10, J4.15, J4.16, J6.2, J8.3, SW1.1, U1.3 (GND), U1.8 (GND), U1.13 (GND), U1.18 (GND), U1.23 (GND), U1.28 (GND), U1.38 (GND); also elsewhere on the board
I2C_SCL: J1.3, R1.2, U1.27 (GPIO21)
I2C_SDA: J1.4, R2.2, U1.26 (GPIO20)
MISO: J4.3, J4.4, U1.21 (GPIO16)
MOSI: J4.7, J4.8, U1.25 (GPIO19)
unnamed: J1.2, J2.2
unnamed: J3.3, U1.34 (GPIO28_ADC2)
unnamed: J3.4, U1.32 (GPIO27_ADC1)
unnamed: J3.5, U1.31 (GPIO26_ADC0)
unnamed: J4.11, J4.12, J9.2
unnamed: J5.1, U1.7 (GPIO5)
unnamed: J7.2, R3.1, SW1.2, U1.30 (RUN)
SCK: J4.5, J4.6, U1.24 (GPIO18)

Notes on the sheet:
Jumper Normal offen
Externe Spannungsversorgung, nur verwenden wenn _kein_ Floppy-Netzteil angeschlossen wird !
Pinbelegung für DrehDrückGeber PIN1: GND PIN2: + PIN3: SW PIN4: DT PIN5: CLK

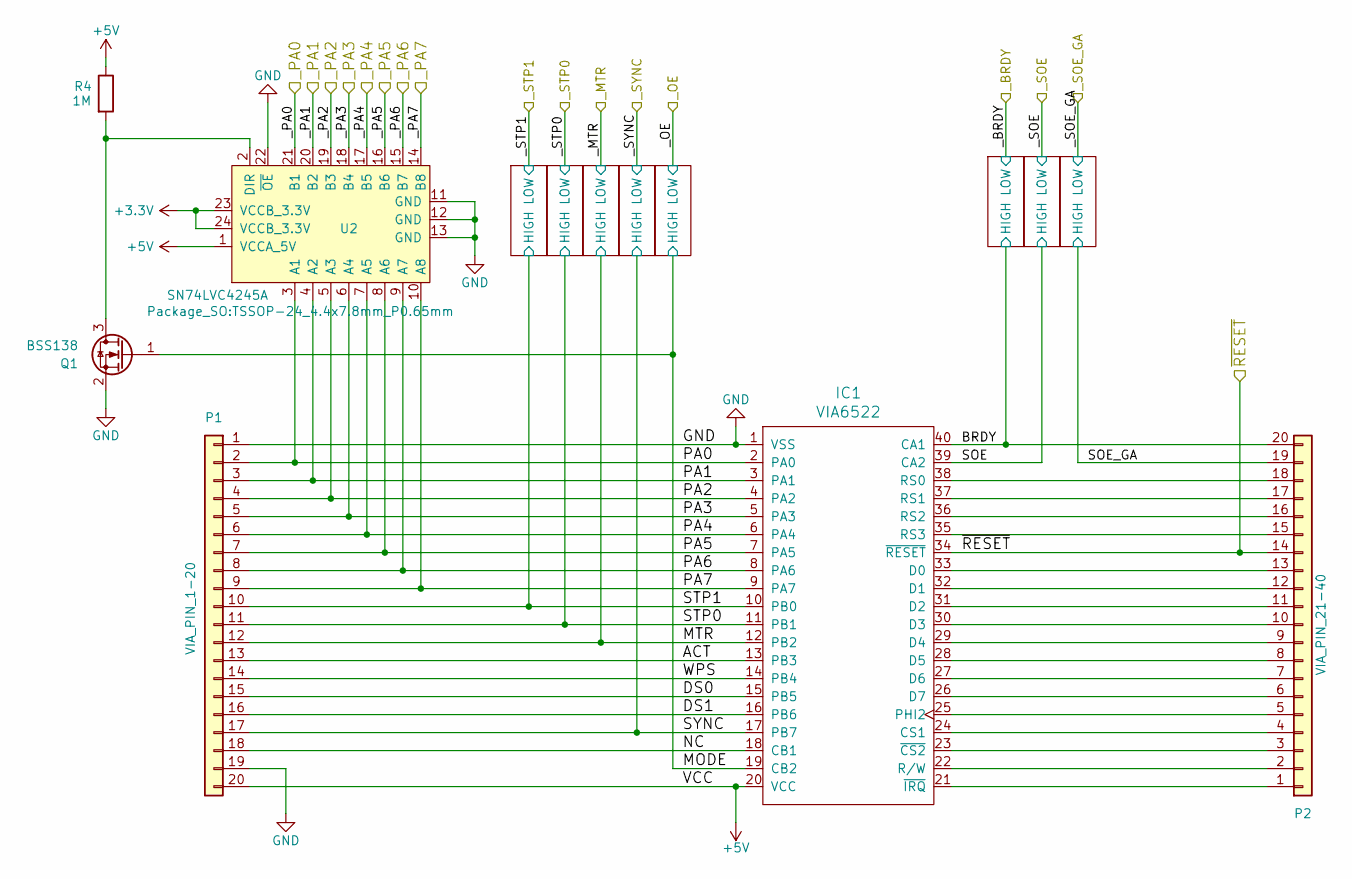
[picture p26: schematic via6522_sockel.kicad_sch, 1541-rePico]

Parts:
IC1: VIA6522; DIP-40_W15.24mm_Socket_LongPads
P1: VIA_PIN_1-20; PinHeader_1x20_P2.54mm_Vertical
P2: VIA_PIN_21-40; PinHeader_1x20_P2.54mm_Vertical
Q1: BSS138; SOT-23
R4: 1M; R_0603_1608Metric
U2: SN74LVC4245A; TSSOP-24_4.4x7.8mm_P0.65mm

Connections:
+3.3V: U2.23 (VCCB_3.3V), U2.24 (VCCB_3.3V); also elsewhere on the board
+5V: IC1.20 (VCC), P1.20, R4.1, U2.1 (VCCA_5V); also elsewhere on the board
/VIA 6522 Sockel/ACT: IC1.13 (PB3), P1.13
/VIA 6522 Sockel/BRDY: IC1.40 (CA1), P2.20; also elsewhere on the board
/VIA 6522 Sockel/DS0: IC1.15 (PB5), P1.15
/VIA 6522 Sockel/DS1: IC1.16 (PB6), P1.16
/VIA 6522 Sockel/MODE: IC1.19 (CB2), Q1.1 (G); also elsewhere on the board
/VIA 6522 Sockel/MTR: IC1.12 (PB2), P1.12; also elsewhere on the board
/VIA 6522 Sockel/NC: IC1.18 (CB1), P1.18
/VIA 6522 Sockel/PA0: IC1.2 (PA0), P1.2, U2.3 (A1)
/VIA 6522 Sockel/PA1: IC1.3 (PA1), P1.3, U2.4 (A2)
/VIA 6522 Sockel/PA2: IC1.4 (PA2), P1.4, U2.5 (A3)
/VIA 6522 Sockel/PA3: IC1.5 (PA3), P1.5, U2.6 (A4)
/VIA 6522 Sockel/PA4: IC1.6 (PA4), P1.6, U2.7 (A5)
/VIA 6522 Sockel/PA5: IC1.7 (PA5), P1.7, U2.8 (A6)
/VIA 6522 Sockel/PA6: IC1.8 (PA6), P1.8, U2.9 (A7)
/VIA 6522 Sockel/PA7: IC1.9 (PA7), P1.9, U2.10 (A8)
/VIA 6522 Sockel/SOE: IC1.39 (CA2); also elsewhere on the board
/VIA 6522 Sockel/SOE_GA: P2.19; also elsewhere on the board
/VIA 6522 Sockel/STP0: IC1.11 (PB1), P1.11; also elsewhere on the board
/VIA 6522 Sockel/STP1: IC1.10 (PB0), P1.10; also elsewhere on the board
/VIA 6522 Sockel/SYNC: IC1.17 (PB7), P1.17; also elsewhere on the board
/VIA 6522 Sockel/WPS: IC1.14 (PB4), P1.14
/VIA 6522 Sockel/~RESET: IC1.34 (~RESET), P2.14; also elsewhere on the board
/_PA0: U2.21 (B1); also elsewhere on the board
/_PA1: U2.20 (B2); also elsewhere on the board
/_PA2: U2.19 (B3); also elsewhere on the board
/_PA3: U2.18 (B4); also elsewhere on the board
/_PA4: U2.17 (B5); also elsewhere on the board
/_PA5: U2.16 (B6); also elsewhere on the board
/_PA6: U2.15 (B7); also elsewhere on the board
/_PA7: U2.14 (B8); also elsewhere on the board
GND: IC1.1 (VSS), P1.1, P1.19, Q1.2 (S), U2.11 (GND), U2.12 (GND), U2.13 (GND), U2.22 (~OE); also elsewhere on the board
unnamed: IC1.24 (CS1), P2.4
unnamed: IC1.33 (D0), P2.13
unnamed: IC1.32 (D1), P2.12
unnamed: IC1.31 (D2), P2.11
unnamed: IC1.30 (D3), P2.10
unnamed: IC1.29 (D4), P2.9
unnamed: IC1.28 (D5), P2.8
unnamed: IC1.27 (D6), P2.7
unnamed: IC1.26 (D7), P2.6
unnamed: IC1.25 (PHI2), P2.5
unnamed: IC1.38 (RS0), P2.18
unnamed: IC1.37 (RS1), P2.17
unnamed: IC1.36 (RS2), P2.16
unnamed: IC1.35 (RS3), P2.15
unnamed: IC1.22 (R/W), P2.2
unnamed: IC1.23 (~CS2), P2.3
unnamed: IC1.21 (~IRQ), P2.1
unnamed: Q1.3 (D), R4.2, U2.2 (DIR)

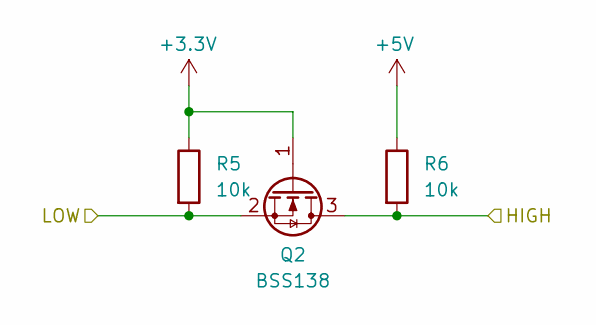
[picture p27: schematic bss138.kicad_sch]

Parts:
Q2: BSS138; SOT-23
R5, R6: 10k; R_0603_1608Metric

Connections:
+3.3V: Q2.1 (G), R5.1; also elsewhere on the board
+5V: R6.1; also elsewhere on the board
/VIA 6522 Sockel/STP1: Q2.3 (D), R6.2; also elsewhere on the board
/_STP1: Q2.2 (S), R5.2; also elsewhere on the board

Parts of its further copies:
Q3, Q4, Q5, Q6, Q7, Q8, Q9: BSS138; SOT-23
R7, R8, R9, R10, R11, R12, R13, R14, R15, R16, R17, R18, R19, R20: 10k; R_0603_1608Metric

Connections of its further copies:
+3.3V: Q3.1 (G), Q4.1 (G), Q5.1 (G), Q6.1 (G), Q7.1 (G), Q8.1 (G), Q9.1 (G), R7.1, R9.1, R11.1, R13.1, R15.1, R17.1, R19.1; also elsewhere on the board
+5V: R8.1, R10.1, R12.1, R14.1, R16.1, R18.1, R20.1; also elsewhere on the board
/VIA 6522 Sockel/BRDY: Q7.3 (D), R16.2; also elsewhere on the board
/VIA 6522 Sockel/MODE: Q6.3 (D), R14.2; also elsewhere on the board
/VIA 6522 Sockel/MTR: Q4.3 (D), R10.2; also elsewhere on the board
/VIA 6522 Sockel/SOE: Q8.3 (D), R18.2; also elsewhere on the board
/VIA 6522 Sockel/SOE_GA: Q9.3 (D), R20.2; also elsewhere on the board
/VIA 6522 Sockel/STP0: Q3.3 (D), R8.2; also elsewhere on the board
/VIA 6522 Sockel/SYNC: Q5.3 (D), R12.2; also elsewhere on the board
/_BRDY: Q7.2 (S), R15.2; also elsewhere on the board
/_MTR: Q4.2 (S), R9.2; also elsewhere on the board
/_OE: Q6.2 (S), R13.2; also elsewhere on the board
/_SOE: Q8.2 (S), R17.2; also elsewhere on the board
/_SOE_GA: Q9.2 (S), R19.2; also elsewhere on the board
/_STP0: Q3.2 (S), R7.2; also elsewhere on the board
/_SYNC: Q5.2 (S), R11.2; also elsewhere on the board

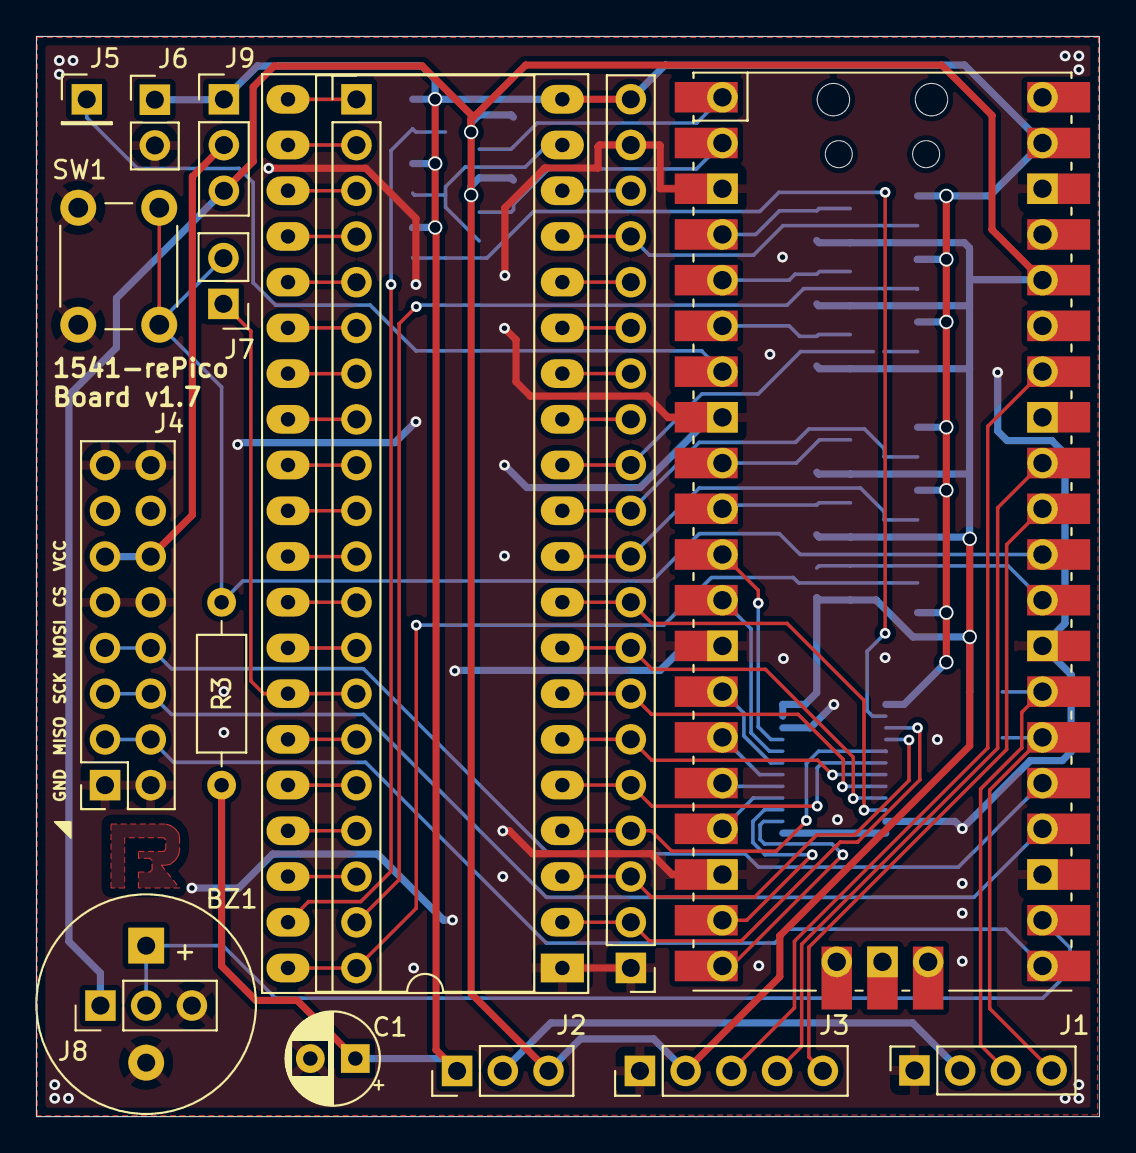
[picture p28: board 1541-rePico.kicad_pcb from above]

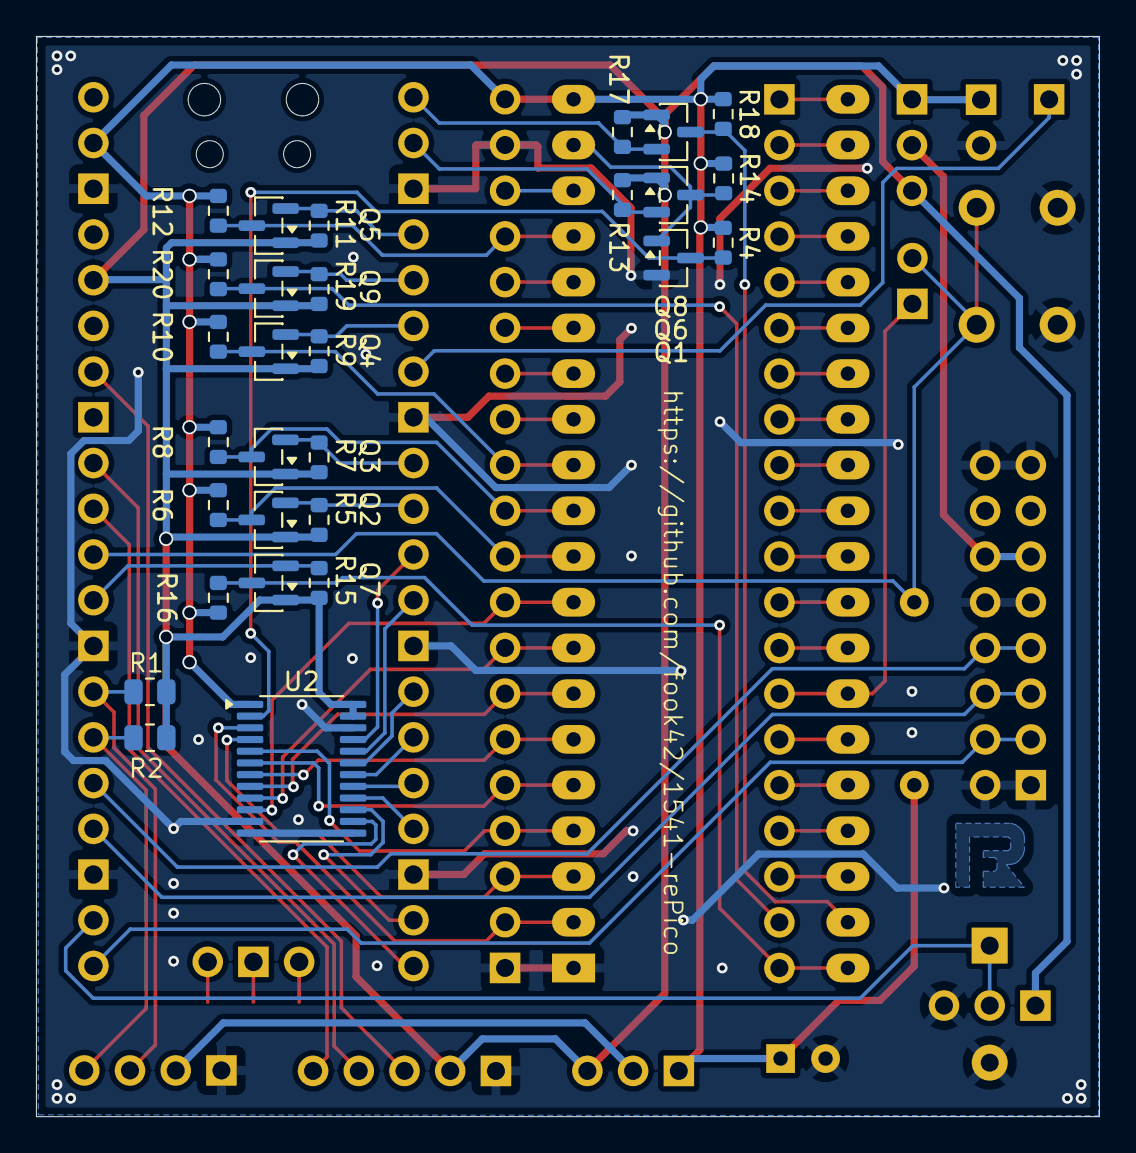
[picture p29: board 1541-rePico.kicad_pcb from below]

Board: 2 copper layers, 59.1 x 60.0 mm, 46 parts (29 on the bottom side), 72 nets.

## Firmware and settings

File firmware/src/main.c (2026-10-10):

/////////////////////////////////////////////////
// 1541-rePico
/////////////////////////////////////////////////
// author: F00K42
// last changed: 2026/07/24
// repo: https://github.com/fook42/1541-rePico
/////////////////////////////////////////////////


#include <stdio.h>
#include "pico/stdlib.h"
#include "hardware/i2c.h"
#include "hardware/timer.h"
#include "hardware/clocks.h"

#include "pinout.h"

#define _EXTERN_

#include "version.h"
#include "display.h"
#include "lcd.h"
#include "oled.h"
#include "i2c.h"
#include "gcr.h"
#include "menu.h"
#include "mymenu.h"
#include "gui_constants.h"
#include "globals.h"
#include "rw_routines.h"
#include "menu_image.h"

#include "hw_config.h"
#include "f_util.h"
#include "ff.h"

#include "main.h"


#define START_MESSAGE_TIME 1500

volatile uint8_t irq_key_value = NO_KEY;

volatile bool input_block = false;

uint64_t key2_down_time=0;
uint8_t num_max_tracks;
uint16_t selected_image_nr = 0xFFFF;

// ---------------------------------------------------------------

int64_t input_debounce_callback(alarm_id_t id, void *user_data)
{
    (void) id;
    (void) user_data;

    input_block = false;
    return 0;
}

void gpio_callback(uint gpio, uint32_t events)
{
    if ((GPIO_STP0==gpio) || (GPIO_STP1==gpio))
    {
        static uint64_t last_int;
        // general gpio-ISR .. triggered for STP0 or STP1 change.. no need to detect the cause
        if ((time_us_64()-last_int) > STEP_MIN_TIME)
        {
            stepper_signal_puffer[stepper_signal_w_pos] = ((bool_to_bit(gpio_get(GPIO_STP0))<<1) | (bool_to_bit(gpio_get(GPIO_STP1))));
            stepper_signal_w_pos++;
        }
        last_int = time_us_64();
    } else {
        if ((NO_KEY == irq_key_value) && (false == input_block))
        {
            if (GPIO_BT3==gpio)
            {
                input_block = true;
                if (events==GPIO_IRQ_EDGE_FALL)
                {
                    irq_key_value = KEY2_DOWN;
                    input_debounce_alarm = add_alarm_in_ms(BUTTON_DEBOUNCE_TIME, input_debounce_callback, NULL, false);
                    key2_down_time = time_us_64();
                } else {
                    uint64_t now_time = time_us_64();
                    if (key2_down_time > now_time)
                    {
                        key2_down_time -= (now_time+1);
                        now_time = ((uint64_t)-1);
                    }

                    if ((now_time-key2_down_time) > TIMEOUT2_KEY2)
                    { irq_key_value = KEY2_TIMEOUT2; }
                    else if ((now_time-key2_down_time) > TIMEOUT1_KEY2)
                    { irq_key_value = KEY2_TIMEOUT1; }
                    else
                    { irq_key_value = KEY2_UP; }

                    key2_down_time = now_time;
                    input_debounce_alarm = add_alarm_in_ms(BUTTON_DEBOUNCE_TIME, input_debounce_callback, NULL, false);
                }
            } else if (GPIO_BT1==gpio)
            {
                input_block = true;
                if (gpio_get(GPIO_BT2))
                {
                    irq_key_value = KEY1_DOWN;
                } else {
                    irq_key_value = KEY0_DOWN;
                }
                input_debounce_alarm = add_alarm_in_ms(ROTARY_DEBOUNCE_TIME, input_debounce_callback, NULL, false);
            }
        }
    }
}

// ---------------------------------------------------------------

int main()
{
    stdio_init_all();

    sleep_ms(500);

    printf("1541repico boot\n");

    if (display_init())
    {
        display_home();
    }

    show_start_message();

    // init input-keys
    init_key_inputs();

    // Stepper Initialisieren
    init_stepper();

    // Motor Initialisieren
    init_motor();

    // Steursignale BYTE_READY, SYNC und SOE Initialisieren
    init_control_signals();

    init_soe_gatearray();
    clear_soe_gatearray();

    init_bytetimer();

    init_writeprot();
    disable_write_protection();

#if PCB_VERSION>=17
    // Enable Sound-Output-Pin
    init_sound();
#endif

    // setup menus
    menu_init(&main_menu,     main_menu_entrys,     count_of(main_menu_entrys),     LCD_LINE_SIZE, LCD_LINE_COUNT);
    menu_init(&image_menu,    image_menu_entrys,    count_of(image_menu_entrys),    LCD_LINE_SIZE, LCD_LINE_COUNT);
    menu_init(&settings_menu, settings_menu_entrys, count_of(settings_menu_entrys), LCD_LINE_SIZE, LCD_LINE_COUNT);
    menu_init(&info_menu,     info_menu_entrys,     count_of(info_menu_entrys),     LCD_LINE_SIZE, LCD_LINE_COUNT);

    menu_set_root(&main_menu);
    // ----

    sleep_ms(START_MESSAGE_TIME);

    display_clear();
    display_home();

    set_gui_mode(GUI_SELECTOR);

    // set root of sd-card as current path
    current_path[0]='/';
    current_path[1]=0;

    while (true) {
        check_stepper_signals();
        update_gui();
    }
}
/////////////////////////////////////////////////////////////////////
/////////////////////////////////////////////////////////////////////

FRESULT mount_sdcard(const char* mount_path)
{
    BYTE mount_option = 1; /* 0=Do not mount (delayed mount), 1=Mount immediately */

    FRESULT fr = f_mount(&fs, mount_path, mount_option);
    if (FR_OK == fr)
    {
        fb_dir_entry_count = get_dir_entry_count(mount_path); // open card, count entries on root level
    }
    return fr;
}

FRESULT umount_sdcard(void)
{
    // reset path for next sd-card mount
    current_path[0]='/';
    current_path[1]=0;
    return f_unmount("");
}

void show_fs_error(FRESULT error_code)
{
    // display_string("f_mount error:");
    // display_data(error_code+'A');
    const char* error_txt=FRESULT_str(error_code);
    size_t err_str_len=strlen(error_txt);
    uint8_t err_str_offset=0;
    irq_key_value = NO_KEY;
    do
    {
        display_setcursor(0, 1);
        display_print(error_txt, err_str_offset++, 16);
        sleep_ms(333);
    }
    while (((err_str_offset+15)<err_str_len) && (irq_key_value != KEY2_DOWN));

    while(irq_key_value != KEY2_DOWN) {};
    irq_key_value = NO_KEY;
    return;
}
/////////////////////////////////////////////////////////////////////


int64_t steppertimer_callback(alarm_id_t id, void *user_data)
{
    (void) id;
    (void) user_data;

    send_byte_ready = false;
    stop_bytetimer();

    // neue track Geschwindigkeit setzen -> timer restart
    akt_track_pos = 0;

    akt_half_track = selected_track&0x7E;

    start_bytetimer(akt_half_track);
    send_byte_ready = true;
    turn_sound_off();

    return 0;
}


void start_stepper_timer(void)
{
    turn_sound_on();

    if (stepper_alarm) { cancel_alarm(stepper_alarm); }
    stepper_alarm = add_alarm_in_ms(STEPPER_DELAY_TIME, steppertimer_callback, NULL, false);
}

/////////////////////////////////////////////////////////////////////

void check_stepper_signals(void)
{
    // Auf Steppermotor aktivität prüfen
    // und auswerten
    if(stepper_signal_r_pos != stepper_signal_w_pos)    // Prüfen ob sich was neues im Ringpuffer für die Steppersignale befindet
    {
        uint8_t stepper = stepper_signal_puffer[(stepper_signal_r_pos+255)&0xFF]<<2;
        stepper |= stepper_signal_puffer[stepper_signal_r_pos];
        stepper_signal_r_pos++;

        switch(stepper)
        {
            case 0b00000011:
            case 0b00000100:
            case 0b00001001:
            case 0b00001110:
                {
                    // DEC
                    stepper_dec();
                    start_stepper_timer();
                }
                break;

            case 0b00000001:
            case 0b00000110:
            case 0b00001011:
            case 0b00001100:
                {
                    // INC
                    stepper_inc();
                    start_stepper_timer();
                }
                break;

            default:
                break;
        }
    }
}

/////////////////////////////////////////////////////////////////////

void init_key_inputs(void)
{
    gpio_init(GPIO_BT1);
    gpio_init(GPIO_BT2);
    gpio_init(GPIO_BT3);
    gpio_set_dir(GPIO_BT1, GPIO_IN);
    gpio_set_dir(GPIO_BT2, GPIO_IN);
    gpio_set_dir(GPIO_BT3, GPIO_IN);
    gpio_set_pulls(GPIO_BT1, true, false);
    gpio_set_pulls(GPIO_BT2, true, false);
    gpio_set_pulls(GPIO_BT3, true, false);
    gpio_set_irq_enabled_with_callback(GPIO_BT1, GPIO_IRQ_EDGE_FALL, true, &gpio_callback);
    gpio_set_irq_enabled(GPIO_BT3, GPIO_IRQ_EDGE_RISE | GPIO_IRQ_EDGE_FALL, true);
}

uint8_t get_key_from_buffer(void)
{
    uint8_t val;

    val = irq_key_value;    // get last detected key
    irq_key_value = NO_KEY; // reset last state - ready for more

    return val;
}

void show_longpress(void)
{
    static uint8_t shown_time_steps;
    uint64_t my_now_time = time_us_64();
    uint64_t my_down_time = key2_down_time;
    char filler;
    if (my_down_time > my_now_time)
    {
        my_down_time -= (my_now_time+1);
        my_now_time = ((uint64_t)-1);
    }

    const uint64_t block_step = TIMEOUT2_KEY2/LCD_LINE_SIZE;
    uint8_t  time_steps = (my_now_time-my_down_time)/block_step;
    filler = display_pointer_char;
    if (time_steps>=LCD_LINE_SIZE) { filler = display_cursor_char; }

    if (shown_time_steps != time_steps)
    {
        display_setcursor(0,2);
        for(int i=0; i<LCD_LINE_SIZE; i++)
        {
            if(i<time_steps)
                display_data(filler);
            else
                display_data(' ');
        }
    }
}

void update_gui(void)
{
    static uint8_t shown_half_track = 255;
    static bool shown_motor_status = false;
    static bool key2_pressed = false;
    static uint32_t wait_counter0 = 0;
    bool new_motor_status;
    uint8_t key_code = get_key_from_buffer();
    char byte_str[8];
    FILINFO next_dir_entry;

    switch (current_gui_mode)
    {
    case GUI_INFO_MODE:

        if(KEY2_UP == key_code)
        {
            key2_pressed = false;
            set_gui_mode(GUI_MENU_MODE);
        } else if(KEY2_TIMEOUT2 == key_code)
        {
            key2_pressed = false;
            // next image...
            if (selected_image_nr<fb_dir_entry_count)
            {
                seek_to_dir_entry(selected_image_nr, current_path);
                FRESULT fr = f_readdir(&dir_object, &next_dir_entry);
                if((0 != next_dir_entry.fname[0]) && (FR_OK == fr))
                {
                    if(!(next_dir_entry.fattrib & AM_DIR))
                    {
                        if (TYPE_VALID == open_dir_entry(next_dir_entry))
                        {
                            ++selected_image_nr;
                            set_gui_mode(GUI_INFO_MODE);
                        }
                    }
                }
            }
        } else if(KEY2_TIMEOUT1 == key_code)
        {
            key2_pressed = false;
        } else if(KEY2_DOWN == key_code)
        {
            key2_pressed = true;
        }
        if (key2_pressed) { show_longpress(); }

        if(shown_half_track != akt_half_track)
        {
            shown_half_track = akt_half_track;
            display_setcursor(disp_trackno_p);
            (void)dez2out((shown_half_track>>1)+1, 2, byte_str);
            display_data(byte_str[0]);
            display_data(byte_str[1]);
        }

        new_motor_status = get_motor_status();
        if(shown_motor_status != new_motor_status)
        {
            shown_motor_status = new_motor_status;
            display_setcursor(disp_motortxt_p);
            if(shown_motor_status)
                display_string(disp_motor_on_s);
            else
                display_string(disp_motor_off_s);
        }

        if((is_image_mount) && (gui_current_line_offset > 0))
        {
            //// Filename Scrolling

            ++wait_counter0;

            if(300000 == wait_counter0)
            {
                wait_counter0 = 0;

                if(0 == gui_line_scroll_end_begin_wait)
                {
                    // Es darf gescrollt werden
                    if(!gui_line_scroll_direction)
                    {
                        ++gui_line_scroll_pos;
                        if(gui_line_scroll_pos >= gui_current_line_offset)
                        {
                            gui_line_scroll_end_begin_wait = 6;
                            gui_line_scroll_direction = 1;
                        }
                    }
                    else
                    {
                        --gui_line_scroll_pos;
                        if(gui_line_scroll_pos == 0)
                        {
                            gui_line_scroll_end_begin_wait = 6;
                            gui_line_scroll_direction = 0;
                        }
                    }

                    display_setcursor(disp_scrollfilename_p);
                    display_print(image_filename,gui_line_scroll_pos,LCD_LINE_SIZE);
                } else {
                    --gui_line_scroll_end_begin_wait;
                }
            }
        }
        break;

    case GUI_MENU_MODE:
        check_menu_events(menu_update(key_code));
        break;

    case GUI_FILE_BROWSER:
        filebrowser_update(key_code);
        break;

    case GUI_SELECTOR:
        if(KEY2_UP == key_code)
        {
            unmount_image();
            set_gui_mode(GUI_MENU_MODE);
            break;
        } else if(KEY2_TIMEOUT2 == key_code)
        {
            // exit_main = 0;
        }

        handle_menu_image();

        if(shown_half_track != akt_half_track)
        {
            shown_half_track = akt_half_track;
            display_setcursor(disp_trackno_p);
            (void)dez2out((shown_half_track>>1)+1, 2, byte_str);
            display_data(byte_str[0]);
            display_data(byte_str[1]);
        }

        new_motor_status = get_motor_status();
        if(shown_motor_status != new_motor_status)
        {
            shown_motor_status = new_motor_status;
            display_setcursor(disp_motortxt_p);
            if(shown_motor_status)
                display_string(disp_motor_on_s);
            else
                display_string(disp_motor_off_s);
        }
        break;

    default:
        break;
    }
}

void check_menu_events(const uint16_t menu_event)
{
    const uint8_t command = (uint8_t) ((menu_event >> 8) & 0xff);
    const uint8_t value = (uint8_t) (menu_event & 0xff);

    FRESULT fr;

    switch(command)
    {
        case MC_EXIT_MENU:
            set_gui_mode(GUI_INFO_MODE);
            break;

        case MC_SELECT_ENTRY:
            switch(value)
            {
                /// Main Menü

                /// Image Menü
                case M_MENU_IMAGE:
                    set_gui_mode(GUI_SELECTOR);
                    break;
                case M_LOAD_IMAGE:
                    fr = mount_sdcard(current_path);
                    display_clear();
                    display_home();
                    if (FR_OK == fr)
                    {
                        set_gui_mode(GUI_FILE_BROWSER);
                    } else {
                        display_string("f_mount error:");
                        display_data(fr+'A');
                        show_fs_error(fr);
                        menu_refresh();
                    }
                    break;

                case M_SAVE_IMAGE:
                    if (is_image_mount)
                    {
                        char byte_str[8];
                        int file_op_status;
                        // todo: create save-file dialog, name, type
                        // for now: open a "standard-file" (G64)
                        fr = mount_sdcard(current_path);
                        display_clear();
                        display_home();
                        if (FR_OK != fr)
                        {
                            display_string("f_mount error:");
                            display_data(fr+'A');
                            show_fs_error(fr);
                            menu_refresh();
                            break;
                        }
                        fr = f_open(&fd, "1541-repico.g64", FA_CREATE_ALWAYS|FA_WRITE);
                        display_string("G64 file open...");
                        if (FR_OK == fr)
                        {
                            display_setcursor(0,1);
                            file_op_status = write_disk(&fd, G64_IMAGE, num_max_tracks);
                            if (file_op_status>0)
                            {
                                (void)dez2out(file_op_status+1,2,byte_str);
                                display_data(byte_str[0]);
                                display_data(byte_str[1]);
                                display_string(" Tracks saved ");
                            } else {
                                display_string("Error:");
                                (void)dez2out(-file_op_status,2,byte_str);
                                display_data(byte_str[0]);
                                display_data(byte_str[1]);
                            }
                        } else {
                            display_setcursor(0,1);
                            display_string("failed !");
                        }
                        f_close(&fd);
                        sleep_ms(3000);
                        display_clear();
                        display_home();
                        fr = f_open(&fd, "1541-repico.d64", FA_CREATE_ALWAYS|FA_WRITE);
                        display_string("D64 file open...");
                        if (FR_OK == fr)
                        {
                            display_setcursor(0,1);
                            file_op_status = write_disk(&fd, D64_IMAGE, num_max_tracks);
                            if (file_op_status>0)
                            {
                                (void)dez2out(file_op_status+1,2,byte_str);
                                display_data(byte_str[0]);
                                display_data(byte_str[1]);
                                display_string(" Tracks saved ");
                            } else {
                                display_string("Error:");
                                (void)dez2out(-file_op_status,2,byte_str);
                                display_data(byte_str[0]);
                                display_data(byte_str[1]);
                            }
                        } else {
                            display_setcursor(0,1);
                            display_string("failed !");
                        }
                        f_close(&fd);
                        sleep_ms(3000);
                        umount_sdcard();
                        menu_refresh();
                    }
                    break;

                case M_UNLOAD_IMAGE:
                    unmount_image();
                    umount_sdcard();
                    set_gui_mode(GUI_INFO_MODE);
                    break;

                case M_RELOAD_DISK:
                    if (is_image_mount)
                    {
                        is_image_mount = false;
                        for(uint8_t i=0; i<LCD_LINE_SIZE; i++)
                        {
                            display_setcursor(i,0);
                            display_data(display_cursor_char);
                            sleep_ms(50);
                        }
                        for(uint8_t i=0; i<LCD_LINE_SIZE; i++)
                        {
                            display_setcursor(i,0);
                            display_data(' ');
                            sleep_ms(50);
                        }
                        is_image_mount = true;
                        set_gui_mode(GUI_INFO_MODE);
                    }
                    break;

                case M_WP_IMAGE:
                    if(menu_get_entry_var1(&image_menu, M_WP_IMAGE))
                    {
                        enable_write_protection();
                    } else {
                        disable_write_protection();
                    }
                    set_gui_mode(GUI_INFO_MODE);
                    break;

                /// Settings Menü
                case M_RESTART:
                    // exit_main = 0;
                    menu_refresh();
                    break;

                /// Info Menü
                case M_VERSION_INFO:
                    show_start_message();
                    while(irq_key_value != KEY2_DOWN) {};
                    irq_key_value = NO_KEY;
                    menu_refresh();
                    break;

                case M_SDCARD_INFO:
                    if (FR_OK == mount_sdcard(current_path))
                    {
                        show_sdcard_info_message();
                        while(irq_key_value != KEY2_DOWN) {};
                        irq_key_value = NO_KEY;
                    } else {
                        display_clear();
                        display_home();
                        display_string("f_mount error:");
                        display_data(fr+'A');
                        show_fs_error(fr);
                    }
                    umount_sdcard();
                    menu_refresh();
                    break;

                default:
                    break;
            }
            break;

        default:
            break;
    }
}

/////////////////////////////////////////////////////////////////////

void set_gui_mode(const uint8_t gui_mode)
{
    current_gui_mode = gui_mode;
    switch(gui_mode)
    {
        case GUI_INFO_MODE:
            infomode_update();
            break;

        case GUI_MENU_MODE:
            menu_refresh();
            break;

        case GUI_FILE_BROWSER:
            filebrowser_refresh();
            break;

        case GUI_SELECTOR:
            handle_menu_image();
            break;

        default:
            break;
    }
}
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

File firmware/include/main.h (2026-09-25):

/**********************************
 * header - main routines, defines, variables
 *
 * Author: F00K42
 * Last change: 2026/07/24
***********************************/
#include "hw_config.h"
#include "f_util.h"
#include "ff.h"
#include "globals.h"

// functions
int64_t input_debounce_callback(alarm_id_t id, void *user_data);

FRESULT mount_sdcard(const char* mount_path);
FRESULT umount_sdcard(void);
void show_fs_error(FRESULT error_code);

void check_stepper_signals(void);
void check_motor_signal(void);

void init_key_inputs(void);
uint8_t get_key_from_buffer(void);
void show_longpress(void);
void update_gui(void);
void check_menu_events(const uint16_t menu_event);
void set_gui_mode(const uint8_t gui_mode);
void filebrowser_update(uint8_t key_code);
void filebrowser_refresh(void);

void infomode_update(void);

void handle_menu_image(void);
void insert_menu_image(char* menu_path);

uint16_t get_dir_entry_count(const char* entrycount_path);
uint16_t seek_to_dir_entry(uint16_t entry_num, const char* seek_path);

void show_start_message(void);
void show_sdcard_info_message(void);

void init_stepper(void);
void stepper_inc(void);
void stepper_dec(void);
void init_motor(void);
void init_control_signals(void);
void init_soe_gatearray(void);

uint8_t open_dir_entry(FILINFO od_file_entry);

uint8_t open_disk_image(FIL* fd, FILINFO *file_entry);
void close_disk_image(FIL* fd);
void unmount_image(void);

void init_writeprot(void);
void send_disk_change(void);

void init_sound(void);

bool repeating_timer_callback(__unused struct repeating_timer *t);
void init_bytetimer(void);
void start_bytetimer(uint8_t half_track);
void stop_bytetimer(void);

int64_t steppertimer_callback(alarm_id_t id, void *user_data);
void start_stepper_timer(void);

/////////////
#define set_byte_ready()    gpio_set_dir(GPIO_BRDY,GPIO_IN)    // HiZ
#define clear_byte_ready()  {gpio_set_dir(GPIO_BRDY,GPIO_OUT);gpio_put(GPIO_BRDY,false);}   // auf Ground ziehen

#define get_soe_status()    gpio_get(GPIO_SOE)

#define get_so_status()     gpio_get(GPIO_OE)

#define set_soe_gatearray()     gpio_put(GPIO_SOE_GA,true)
#define clear_soe_gatearray()   gpio_put(GPIO_SOE_GA,false)

// WPS will be generated via inverter 74ls04 on 1541*-mainboard
// ... thus we send the inverse here (clear_wps = "1" on WPS)
#define clear_wps()          gpio_set_dir(GPIO_WPS,GPIO_IN)    // HiZ
#define set_wps()           {gpio_set_dir(GPIO_WPS,GPIO_OUT);gpio_put(GPIO_WPS,false);}   // pull low

#define get_motor_status()  gpio_get(GPIO_MTR)

#define set_sync()          gpio_put(GPIO_SYNC,true)
#define clear_sync()        gpio_put(GPIO_SYNC,false)

#define out_gcr_byte(gcr_byte)  gpio_put_masked(PAPORT_MASK,gcr_byte<<GPIO_PAPORT)
#define in_gcr_byte()       (gpio_get_all()&PAPORT_MASK)>>GPIO_PAPORT

#define enable_write_protection()   {clear_wps();floppy_wp=true;}
#define disable_write_protection()  {set_wps();floppy_wp=false;}

#if PCB_VERSION>=17
#define turn_sound_on()     gpio_put(GPIO_SND,true)
#define turn_sound_off()    gpio_put(GPIO_SND,false)
#else
#define turn_sound_on()     {}
#define turn_sound_off()    {}
#endif

// Filesystem-variables:
FATFS       fs;             // filesystem handle - only created once
DIR         dir_object;
FIL         fd;             // file descriptor for every open file
FILINFO     fb_dir_entry[LCD_LINE_COUNT];
//
//
#define ROTARY_DEBOUNCE_TIME    (200)
#define BUTTON_DEBOUNCE_TIME    (100)

alarm_id_t input_debounce_alarm = 0;
// timer_t key_longpress_timer;

volatile uint16_t akt_track_pos = 0;

uint8_t selected_track;     // this holds the selected tracknumber
volatile uint8_t akt_half_track;     // this will be the one to be transfered
uint8_t old_half_track;

// timer definition

struct repeating_timer bytetimer;


char image_filename[256]; //Maximal 256 Zeichen
char current_path[512];

uint8_t current_gui_mode;

uint8_t gui_current_line_offset;         // >0 dann ist der Name länger als die maximale Anzeigelaenge
uint8_t gui_line_scroll_pos;             // Kann zwischen 0 und fb_current_line_offset liegen
uint8_t gui_line_scroll_direction;       // Richtung des Scrollings
uint8_t gui_line_scroll_end_begin_wait;

// Alles für den FilebrowserSS
uint16_t fb_dir_entry_count = 0;         // Anzahl der Einträge im aktuellen Direktory
uint8_t fb_cursor_pos = 0;               // Position des Cursors auf dem LCD Display
uint8_t fb_window_pos = 0;               // Position des Anzeigebereichs innerhablb der Menüeinträge

uint8_t fb_current_line_offset = 0;         // >0 dann ist der Name länger als die maximale Anzeigelaenge
uint8_t fb_line_scroll_pos = 0;             // Kann zwischen 0 und fb_current_line_offset liegen
uint8_t fb_line_scroll_direction = 0;       // Richtung des Scrollings
uint8_t fb_line_scroll_end_begin_wait = 10;


// floppydisk emulation
uint8_t akt_image_type = UNDEF_IMAGE;     // 0=kein Image, 1=G64, 2=D64, 3=Selector
bool is_image_mount;
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

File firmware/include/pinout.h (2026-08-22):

/**********************************
 * header - pinout assignment for Pico2 to baseboard
 *
 * Author: F00K42
 * Last change: 2026/07/24
***********************************/
#include "hardware/spi.h"

// Via connection
#define GPIO_SOE    0
#define GPIO_OE     1
#define GPIO_SYNC   2
#define GPIO_SOE_GA 3
#define GPIO_MTR    4
#define GPIO_WPS    5
#define GPIO_STP0   6
#define GPIO_STP1   7

#define GPIO_PAPORT 8  //defines the first bit of 8
#define PAPORT_MASK (uint32_t)(0xFF<<GPIO_PAPORT)
/*
#define GPIO_PA0    8
#define GPIO_PA1    9
#define GPIO_PA2    10
#define GPIO_PA3    11
#define GPIO_PA4    12
#define GPIO_PA5    13
#define GPIO_PA6    14
#define GPIO_PA7    15
*/

// SPI defines
#define SPI_PORT    spi0
#define SPI_MISO    16
#define SPI_SCK     18
#define SPI_MOSI    19

// I2C defines
#define I2C_PORT    i2c0
#define I2C_SDA     20
#define I2C_SCL     21

// 3 für den Drück-Dreh-Schalter
#define GPIO_BT1    27
#define GPIO_BT2    26
#define GPIO_BT3    28

#define GPIO_BRDY   22

#define NOT_CONNECTED (-1)


#if PCB_VERSION>=17
#define GPIO_SND    17
#define SPI_CS      NOT_CONNECTED
#else
#define GPIO_SND    NOT_CONNECTED
#define SPI_CS      17
#endif

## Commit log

2025-10-27 first commit with basics
    folder-structure established
    pcb-layout added
    firmware based on blink-example
    verified i2c-display routines
    added no-OS-FatFS lib as submodule
    [1541-rePico.kicad_pcb, 1541-rePico.kicad_sch, via6522_sockel.kicad_sch]
2025-10-31 updated PCB layout
    [1541-rePico.kicad_pcb, 1541-rePico.kicad_sch]
2025-12-18 added schematic as pdf
2026-01-07 added more 1541-gpios and timer-ISR
2026-01-13 updated schematics&pcb - version 1.1
    [1541-rePico.kicad_pcb, 1541-rePico.kicad_sch, via6522_sockel.kicad_sch]
2026-01-13 fixed input and code cleanup
    removed pio-code - access to variables blocked the system
    fixed interrupt routines for stepper and track handling
    [gui_constants.h, main.c, main.h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]
2026-02-07 major testing
    - removed sprintf, replaced with dec2out (IT2)
    - tracks from 0 to 41 (no dead buffers)
    - stepper reworked (no direct steps, but after 193*byte_ready)
    [main.c, main.h]
2026-02-09 bigger mod
    - stepper wait done via alarm method
    - removed debug-output
    - change of input debouncing (not perfect)
2026-02-10 fixed disk-change
    cleanup of write-protection-signal
    renamed functions to "enable_.." and "disable.."
    for better readability
    [main.c, main.h]
2026-02-11 fix WPS cross-driving
    connection between 1541-board and VIA cut off
    no cross driving of existing 74LS04 and Pico avoided
    [1541-rePico.kicad_pcb, 1541-rePico.kicad_sch, via6522_sockel.kicad_sch]
2026-02-11 updated kicad-data for PCB v1.2
    [1541-rePico.kicad_pcb, 1541-rePico.kicad_sch, via6522_sockel.kicad_sch]
2026-02-11 input irq routine reworked
    removed "counter" value to detect rotary input
    simplyfied by KEY-values that are set
    debounce/blocking mechanism with alarm-timer
    fixes issue #3
    [main.c, main.h]
2026-02-15 new PCB layout + BRDY fix
    changed rotary-encoder connector to default 5 pin
    flipped BRDY signal (GPIO28) with BT3 (GPIO22) to
    not violate 5V tollerance of GPIO28.
    [1541-rePico.kicad_pcb, 1541-rePico.kicad_sch, via6522_sockel.kicad_sch]
2026-02-15 added documents for new PCB1.3 pinout
2026-02-15 enabled image-write-routine
    SAVE_IMAGE will dump current gcr-data
    filename and type is fixed to
    1541-repico.g64 and G64 format
    [main.c]
2026-02-16 new PCB layout to support WPS external
    invert WPS signal to be used as input of photo-sensor
    circuit of 1541-main pcb.
    avoids the concurrent access of the WPS signal between
    GateArray and VIA - now this comes from 74LS04
    [1541-rePico.kicad_pcb, 1541-rePico.kicad_sch, via6522_sockel.kicad_sch]
2026-02-17 updated kicad-files for gerber creation
    [1541-rePico.kicad_pcb]
2026-03-14 SD card handling modified
    moved SD-card mounting to subroutine
    access on each "file-browser" activation
    added sd-card info display
2026-03-26 updated to version 1.4.0
    input-button handling improved: longpress for "back" function
    menu structure adopted: back entry added
    changed startup: sd-card mounting only when accessing images
    write-protect mode changed accordingly to PCB change (WPS jumper wire)
    added sd-card info-screen: partition infos .. but not much yet
    improved oled-output: brighter output on 128x64 oled (double scanline)
2026-03-28 new PCB version 1.5
    - added levelshifter ics txs0108epwr between pico and via pins
    - added pullup-resistors for I2C (populate if necessary)
    - aligned footprint of jumper-headers on 50mil grid
    - added version-text and URL on backside
    [1541-rePico.kicad_pcb, 1541-rePico.kicad_sch, via6522_sockel.kicad_sch]
2026-04-03 minor updates to pcb
    [1541-rePico.kicad_pcb]
2026-04-12 PCB version 1.6
    - use of SN74LVC4245A for levelshifting of PortB-Signals
    -> needed an inverted Mode/OE signal for DIR (done via BSS138)
    - use of BSS138 for shifting of basic signals (MTR, STP,...)
    - cut off "mode/OE" pin from Gatearray -> tied to GND to not let it drive PortB
    - rerouted the PCB again -> alignment of Pinheaders and vias
    [1541-rePico.kicad_pcb, 1541-rePico.kicad_sch, bss138.kicad_sch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]
2026-04-13 updated PDFs for PCB v1.6
    [1541-rePico.kicad_pcb, 1541-rePico.kicad_sch, bss138.kicad_sch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]
2026-05-25 Selector image (#16)
    * creation of selector image
    data-file will be created from sdcard-filelist
    virtual image will be created with bam+dir+data-file
    * fixed manual branch-mix
    * included selector.prg to virtal menu-image
    added cmake-step to convert binary to headerfile for menu.prg
    added generic transfer function from binary to sector/tracks
    added directory-generation
    * create selector-image on boot
    * small change/fix to menu.prg
    * included a Selector-View
    added menu-entries for Selector
    added new function to convert gcr-track to d64 buffer
    moved open-dir-entry routine to a separate function
    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
    [gui_constants.h, main.c, main.h]
2026-06-04 corrections for code-checker findings
    [main.c]
2026-06-11 added re-insert function
2026-06-14 bugfix stepper_buffer overflow
2026-06-15 fixed code analysis findings
    [main.c]
2026-06-20 added low-pass filter for stepper-signals (freespin-demo)
    stepper movement is now only possible if min. 5ms are between
    stepping changes. real hardware will not respond to this, but may make
    some noise (=sound)
    this enables the freespin-demo to be running well - only "real" head-movement
    will be simulated.
    [main.c]
2026-06-21 code refactoring, small fix for PRG size value
    removed some unused variables
    changed code structure in rw-routines
    fixed prg-len calculation (size/254 instead of 253)
    bumped version to 1.6.2
    [main.c, main.h]
2026-07-08 Feature/show longpress (#22)
    * first show-longpress
    * second long-press visu
    * show of longpress fixed
    * changed filler-char when done
    [main.c, main.h]
2026-07-10 added folder-up fixes
    manual filebrowser now reacts on longpress with "folder up" action
    fixed some image-selection counting and handling of ".." entries
    [main.c]
2026-07-10 moving up and down the folder levels fixed
    [main.c]
2026-07-17 basic support for speed settings in g64 files
    track based speed setting (see G64.TXT) supported
    creation of "default" speed zones implemented
2026-07-31 Add CAD-Files for 1541 Bezel
    [1541_Bezel.stp, 2xSide_Holder_LR.stp, Knob.stp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]
2026-08-01 first attempt to enable sound output for stepper
    addresses issue #21
    concept:
    - remove SPI_CS signal from sdcard-adapter - directly connect to GND
    - connect GPIO 17 to + of a Buzzer-device (which creates a tone automatically,
    no PWM needed for now)
    - reuse GPIO 17 now for sound-output
    -> turn on, when stepper movement is detected/started
    turn off, when blocking-timer is done
    [hw_config.c, main.c, main.h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]
2026-08-01 modified PCB for Sound-connector
    updated PCB to version 1.7
    changes include:
    - removal of SW-DBG header
    - addition of Buzzer-connector
    - changed layout of display-connector (straight vs. square)
    [1541-rePico.kicad_pcb, 1541-rePico.kicad_sch, bss138.kicad_sch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]
2026-08-06 PCB 1.7 fixes and files
    updated PCB 1.7 layout:
    - rotated SDCard connector
    - placed silkscreen text for orientation
    - added buzzer-footprint
    updated pdf for SCH and PCB files
    [1541-rePico.kicad_pcb, 1541-rePico.kicad_sch, bss138.kicad_sch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]
2026-08-06 added interactive BOM
2026-08-22 added cmake variable PCB_VERSION
2026-08-22 moved PCB v1.6 to separate folder
    [1541-rePico.kicad_pcb, 1541-rePico.kicad_sch, bss138.kicad_sch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]
2026-08-22 Update pin assignments and stand date in documentation
    Updated the stand date and modified pin assignments for the CS and SOUND.
2026-09-12 update PCB to V1.7.0
    added jumper-selector for SD-Card VCC (3.3V vs 5V)
    slight movements of Buzzer, SDCard-header
    changed Footprint of Buzzer to fit passive Buzzer-pin distance
    [1541-rePico.kicad_pcb, 1541-rePico.kicad_sch, bss138.kicad_sch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]
2026-09-12 pcb V1.7.0 small changes, updated bom
    [1541-rePico.kicad_pcb]
2026-09-12 added JLCPCB ordering files
    [1541-rePico.kicad_pcb, 1541-rePico.kicad_sch, 1541rePico_V170-Bom-bottom.csv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]
2026-09-23 minor fixes menu.prg for C16
    [menu.asm]
2026-09-25 fixed subfolder handling with onscreen menu
    [main.c, main.h]
2026-10-10 timing fix for backchannel, bump version to 1.7.2
    [main.c]
2026-10-24 chore: import CMake presets from pcb16-build
2026-10-24 feature: build legacy PCB16 in workflow
2026-11-01 added HW assembly docs and pictures
2026-11-02 Revise VIA IC-designator and cable connection details
    Updated VIA IC-designator information and corrected cable connection details for the 1541 device.
2026-11-03 HWdocs - added jumpers/connectors and 1541-1 and -2 images
2026-11-08 Update HWSetup.md with CAD files and images
    Added a section for CAD files and images in HWSetup.
